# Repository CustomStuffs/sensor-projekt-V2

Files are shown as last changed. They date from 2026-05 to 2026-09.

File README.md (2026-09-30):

# Sensor Hub

Outdoor environmental monitoring system built on a Raspberry Pi Pico W. Sensors are read every 30 minutes, uploaded over WiFi to a FastAPI server running on a Raspberry Pi, and displayed in a browser dashboard.

## System overview

```
Pico W (MicroPython)
  └─ POST JSON ──► RPi FastAPI server (port 8080)
                      └─ SQLite DB
                      └─ Static files ──► Browser dashboard
```

Remote access via Tailscale VPN — no port forwarding, no auth layer needed.

## Sensors

| Sensor | Chip / interface | Board connection | Measures |
|---|---|---|---|
| Temperature | DS18B20, 1-Wire (GP8) | W1 (J2) | °C |
| Humidity | DHT22, GP9 | W2 (J3) | % RH + °C fallback |
| pH | AD8603 buffer → ADS1115 AIN0 (I2C, GP2/3) | BNC (J1), guarded input | pH 0–14 |
| Light | VEML7700, I2C (GP2/3) | on the board, under a light pipe to the lid | lux |
| Soil moisture | Capacitive, Pico ADC (GP26) | J11 solder holes (GP26–28) | % |
| Motion | PIR, GP11 (also wake IRQ), power-gated by GP12 | W3 (J4) | boolean |
| Water level | Float switch, GP16 | W4 (J5) | float |
| Probe temperature | NTC → ADS1115 AIN1 | J8 pins 3/4 | °C (for compensation) |
| EC | **not on the v1 board** (LMP91200 is EOL; firmware driver exists, keep `ec` disabled) | — | µS/cm |

All sensor fields are nullable — unconnected sensors send `null`.

## Relays (two on-board channels)

The PCB carries **two independent SPDT relays** (K1 on GP10, K2 on GP15), rated 230 VAC / 5 A with reinforced insulation to the sensor side, as a hard minimum. Both relays can be switched and scheduled from the dashboard, and local sensor rules can target either one (`"relay": 2` in a rule; default is relay 1). This allows two simultaneous actuator channels (e.g. pump + valve) without external modules. Future board variants can add more relays.

- **Auto rules**: threshold-based (e.g. water when soil < 30 %) configured in `firmware/src/config.json`
- **Schedule**: time-based rules, also in `config.json`
- **Manual override**: one-click from the dashboard, queued via server command API

## Repo layout

```
firmware/   MicroPython source + flash/dev tools
server/     FastAPI app, SQLite schema, systemd unit
dashboard/  Vanilla HTML/JS/CSS frontend
hardware/   KiCad project + generation scripts, BOM, JLCPCB order files
```

Each folder has its own `CLAUDE.md` with subproject-specific rules.

## Getting started

### Firmware

Requires MicroPython 1.28+ (`RPI_PICO_W` build).

```bash
cd firmware
bash tools/setup.sh          # install mpremote, check device
cp src/config.json.example src/config.json   # fill in WiFi + server URL
bash tools/flash.sh          # copy all files to device
bash tools/monitor.sh        # watch serial output
```

For daily development, use the mount workflow instead of reflashing:

```bash
bash tools/mount.sh   # edits in src/ take effect on Ctrl-D
```

### Server

```bash
cd server
pip install -r requirements.txt
uvicorn api.main:app --host 0.0.0.0 --port 8080
```

Or run as a systemd service:

```bash
sudo cp sensor_hub.service /etc/systemd/system/
sudo systemctl enable --now sensor_hub
```

### Dashboard

Served as static files by the FastAPI server — no build step. Open `http://<pi-ip>:8080` in a browser.

### Hardware

100 × 100 mm, 2-layer PCB (`hardware/kicad/`), generated and routed by the scripts in `hardware/tools/`. JLCPCB fabricates the board and places all SMD parts (`hardware/fab/`, regenerate with `python3 hardware/tools/jlc_export.py`); the through-hole parts — Pico WH sockets, relays, Wago push-in terminals, BNC, X2 capacitors, UART header — are hand-soldered. Details: `hardware/CLAUDE.md` and `hardware/docs/`.

## Pico W hardware notes

- **VSYS ADC**: use `ADC(29)` (GPIO29), not `ADC(3)`. On Pico W, GPIO29 is the VSYS/3 voltage divider. `ADC(3)` reads GPIO3 (I2C SCL) and gives garbage.
- **VSYS measurement timing**: read VSYS *before* `wlan.active(True)` — GPIO29 is shared with the WiFi SPI bus and returns wrong values while the radio is up.
- **Lightsleep after WiFi**: `machine.lightsleep(ms)` can fail silently on Pico W after WiFi use. The firmware falls back to `time.sleep()` automatically and logs when this happens.
- **Serial monitor**: uses `mpremote` (`bash tools/monitor.sh`), not minicom. On immutable distros (Bazzite/Silverblue), minicom is not available.
- **Flashing**: the device enters lightsleep ~30 s after boot, making `mpremote` unreachable. Flash immediately after plugging in USB, or interrupt via REPL first.

## Power budget (battery operation)

| State | Current |
|---|---|
| Lightsleep | 0.30 mA |
| Sensing (all sensors) | 25 mA |
| WiFi active | 80 mA |
| **Average (30 min cycle)** | **~1.2 mA** |

A 10 000 mAh power bank lasts roughly 6–11 months.

## License

MIT

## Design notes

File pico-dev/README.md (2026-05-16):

# Pico UART Debug Bridge

Two-Pico setup: **Machine Pico** (USB→PC) acts as a relay-reset + UART bridge
for the **Project Pico** (running the real firmware, never overwritten directly).

## Hardware

| Machine Pico | → | Project Pico |
|---|---|---|
| GPIO 4 (UART1 TX) | → | GPIO 1 (UART0 RX) |
| GPIO 5 (UART1 RX) | ← | GPIO 0 (UART0 TX) |
| GND | — | GND |
| GPIO 15 → Relay1 IN | | Relay1 COM → RUN pin, NO → GND |
| GPIO 28 → Relay2 IN | | Relay2 COM/NO → light circuit |

Both relays are active-LOW: GPIO LOW = relay closed.
- Relay1 (GPIO 15): pulls Project Pico RUN to GND → hard reset.
- Relay2 (GPIO 28): controls the light switch circuit.

## Quick Start

### 1. Flash the Machine Pico

Connect **only** the Machine Pico via USB.  Hold BOOTSEL, plug in → drag
`machine_pico/main.py` on using Thonny or mpremote:

```bash
mpremote connect /dev/ttyACM0 cp machine_pico/main.py :main.py
```

After reboot the Machine Pico prints `[bridge] ready …` on USB serial.

### 2. Install PC tool dependencies

```bash
pip install -r tools/requirements.txt
```

### 3. Use pico_tool.py

```bash
# Stream all Project Pico output live (also lets you type RESET / SEND:)
python tools/pico_tool.py monitor

# Hard-reset Project Pico via relay
python tools/pico_tool.py reset

# Copy a file to Project Pico (requires confirmation + Project Pico USB connected)
python tools/pico_tool.py flash firmware/src/main.py

# Force a specific port (skips auto-detect)
python tools/pico_tool.py --port /dev/ttyACM1 monitor
```

### 4. Add UART debug output to Project Pico (optional)

Copy `project_pico/uart_debug.py` to the Project Pico:

```bash
mpremote connect /dev/ttyACMx cp project_pico/uart_debug.py :uart_debug.py
```

Then make `uart_debug` the **first import** in `main.py`:

```python
import uart_debug   # must be first — mirrors all print() to UART

# ... rest of your firmware unchanged
```

All `print()` calls are now mirrored to UART0 and will appear in `pico_tool.py monitor`.
Call `uart_debug.tick()` once per loop iteration for a 10 s heartbeat.

## Command Protocol (Machine Pico ↔ PC)

These are the raw commands the Machine Pico understands over its USB serial.
`pico_tool.py` sends them automatically; you can also type them in monitor mode.

| Command | Effect |
|---|---|
| `RESET` | Closes relay1 100 ms → Project Pico RUN → GND → hard reset |
| `SEND:<text>` | Sends `<text>\r\n` to Project Pico via UART |
| `LIGHT_ON` | Closes relay2 (GPIO 28 LOW) → light on |
| `LIGHT_OFF` | Opens relay2 (GPIO 28 HIGH) → light off |
| `LIGHT_TOGGLE` | Toggles relay2 state |

## Flash Workflow (how `flash` works internally)

1. Confirms with user before touching anything
2. Sends `RESET` to Machine Pico (relay fires, Project Pico reboots)
3. Waits 2 s for MicroPython REPL to come up on Project Pico
4. Runs `mpremote connect <project-port> cp <file> :<file>` to copy the file

**Requirement**: the Project Pico must also be connected via USB during flashing
so mpremote can reach its filesystem.

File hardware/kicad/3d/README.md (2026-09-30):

# 3D models (not in git)

KiCad ships no 3D models for these parts, and the vendor models may not be
redistributed (vendor terms of use), so the STEP files are `.gitignore`d.
Download them once into this folder under exactly these names;
`tools/place_pcb.py` points the footprints at `${KIPRJMOD}/3d/<name>` and
sets rotation/offset for each.

| File name | Part | Used by | Source (format: STEP AP214) |
|---|---|---|---|
| `Wago_2601-1102.step` | Wago 2601-1102 | J9 | wago.com → product → CAD (partcommunity); entry "2601-1102 bis 2601-1112", pick 1102 |
| `Wago_2601-1103.step` | Wago 2601-1103 | J2–J6 | same entry, pick 1103 (not the colour-coded 2601-1103/987-100) |
| `Wago_2601-1104.step` | Wago 2601-1104 | J8 | same entry, pick 1104 |
| `Wago_236-403.step` | Wago 236-403 | J7, J10 | wago.com → 236-403 → CAD |
| `Omron_G2RL-14-E.step` | Omron G2RL-14-E DC5 | K1, K2 | TraceParts / omron.com (the sealed -14-E; same body and pins as the -1-E we fit) |
| `TE_BNC_1-1478035-0.step` | TE 1-1478035-0 | J1 | te.com → 1-1478035-0 → Customer View Model `…3d_stp.zip` |

Only the model files matter for the 3D view and the enclosure design; Gerbers
and the JLCPCB files do not depend on them.

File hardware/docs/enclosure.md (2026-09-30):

# Enclosure & Weatherproofing

---

## Primary Recommendation: Hammond 1554T2GYCL

| Attribute | Value |
|---|---|
| Part number | 1554T2GYCL |
| External dimensions | 115 × 65 × 40 mm |
| Material | Polycarbonate (PC) |
| IP rating | **IP67** (1 m submersion) |
| Lid | Clear polycarbonate |
| Color | Light grey body |
| PCB standoffs | 4× M3 brass inserts, 3 mm height |
| Approx. CHF | 8–12 (Distrelec / Conrad) |
| Screws | 4× M3 × 10 mm stainless |

The clear lid lets you see the status LED without drilling.

**Alternative**: Bopla Euromas II EM 220 F (IP65, 122 × 72 × 55 mm, ABS, more depth for wiring).

---

## Cable Entries

| Entry | Part | IP rating | Cable dia. | Qty | Notes |
|---|---|---|---|-----|---|
| Wago sensor cables | Wiska ClikPlug M16 | IP68 | 4–8 mm | 5 | One per sensor port W1–W5 (J2–J6) |
| NTC probe cable (J8) | Wiska ClikPlug M16 | IP68 | 4–8 mm | 1 | 2 wires used in v1 (EC wires unused); M20 if a 4-wire EC probe cable is kept for v2 |
| USB-C power | Bulgin PX0441/B/4M00 | IP68 | Panel mount | 1 | 5V input feedthrough |
| pH BNC external | Amphenol 31-221-RFX | IP67 | Panel mount | 1 | External probe connector |
| Relay mains cables (W6, W7) | Wiska ClikPlug M20 | IP68 | 8–14 mm | 2 | 230 VAC load cables; enter on the MAINS side of the box, away from sensor glands |

**Mains wiring inside the enclosure**: keep 230 VAC load cables on the MAINS side of the box, tied down so a loose conductor cannot reach the SELV side of the PCB. Double-insulated cable (sheath stripped only as far as needed at W6/W7). If the enclosure has any metal parts (e.g. mounting plate), they must be earthed by the electrician.

**⚠ Enclosure size**: the PCB is now **100 × 100 mm**; the Hammond 1554T2GYCL (115 × 65 × 40 mm external) above does **not** fit it, neither does the Bopla EM 220 F. The plan (see `pcb_guidelines.md`) is a 3D-printed enclosure; a bought box needs ≥ ~110 × 110 mm inside and ≥ ~25 mm clear height above the board.

---

## PCB Envelope (for the enclosure design)

Heights above the top of the PCB, from the vendor 3D models (`kicad/3d/`):

| Part | Where on the board | Height |
|---|---|---|
| BNC J1 (pH) | left edge, y 44–60, opening points out of the left edge | ≈ 19.2 mm (tallest) |
| Relays K1/K2 | right half, x 67–80 | 15.7 mm |
| Wago 2601 (J2–J6, J8, J9) | bottom edge row + J9 at the top edge | ≈ 15.1 mm, orange levers reach ~0.8 mm past the board edge |
| Pico WH on sockets | centre, USB-C at the top edge (x ≈ 40) | ≈ 8.5 mm socket + Pico + USB plug |
| Wago 236-403 (W6/W7) | right edge, y 15–51 | 12.7 mm |
| X2 caps C19/C20 | left of the relays | box 13 × 6 mm, check the fitted part |

- **Board mounting**: 4× M3 holes H1–H4 at (3.5, 3.5), (3.5, 96.5), (96.5, 96.5), (96.5, 3.5) mm from the top-left corner.
- **Wire entries**: all sensor terminals (J8, J2–J6) open toward the bottom edge, J9 (5 V) toward the top edge, W6/W7 (mains) toward the right edge — put the glands on those walls and keep the mains glands on the right wall only.
- **Light sensor window**: U6 (VEML7700) is at (45.0, 73.45) mm. A light pipe (acrylic/PMMA rod, ≈ 5–6 mm) runs from just above U6 (≤ 0.5 mm gap) straight up to a window/hole in the lid. Its 3D-printed holder screws to the board through 3× M2 holes H5 (45.0, 66.45), H6 (38.94, 76.95), H7 (51.06, 76.95); the holder base needs a recess for U6 (2.35 mm high) and C9 (3.2 mm below U6). Seal the rod in the lid (silicone or O-ring) and keep it opaque around the sides so only the window collects light.

---

## BNC Panel Mount

The PCB uses a right-angle PCB-mount BNC (TE 1-1478035-0) at the left board edge for internal connection. The external BNC on the enclosure wall is a separate panel-mount connector connected via a short RG174 coaxial pigtail (50–100 mm).

1. Drill a 10 mm hole in the enclosure wall at the BNC position
2. Insert panel-mount BNC (Amphenol 31-221-RFX), secure with lock nut and washer
3. Solder a 75–100 mm RG174 pigtail: center conductor to PCB BNC center pin, shield to PCB BNC shell / VREF_MID trace
4. Apply silicone sealant around the BNC nut on the outside

---

## Gore-Tex Vent Plug (mandatory for outdoor use)

**Part**: Wiska VMK 16 or equivalent IP67-rated vent plug.

**Why**: a fully sealed IP67 enclosure experiences pressure/temperature cycling outdoors. Without a vent, warm air inside the enclosure during the day creates condensation when it cools at night. The Gore-Tex membrane passes water vapor but not liquid water — preventing internal condensation without compromising weather protection.

Install one vent plug in the bottom face of the enclosure (lowest point for drainage if any moisture enters).

---

## Assembly Notes

1. Drill all holes using a step drill bit in polycarbonate — avoid twist drills (crack risk)
2. Install cable glands hand-tight, then 1/4 turn with pliers — do not overtighten
3. Apply silicone sealant (neutral cure, not acetic acid cure) around:
   - PCB standoff mounting screws
   - BNC lock nut
   - USB-C panel connector
4. Route sensor cables with a drip loop before entering cable glands (prevents water tracking)
5. Lid torque: finger-tight + 1/4 turn — overtightening cracks polycarbonate lid
6. Supplied gasket is replaceable; check condition annually if unit is in direct rain exposure
7. Label cable glands with UV-stable vinyl labels or permanent marker (sensor type)

---

## Mounting

Mount on a stake, post, or bracket using M3/M4 stainless bolts through the enclosure wall or base. Avoid mounting flat against a wall — leave at least 10 mm air gap behind for heat dissipation.

Orientation: BNC connector side toward the nearest sheltered location (garden wall, planter edge) to protect the pH probe connection from direct rain impact.

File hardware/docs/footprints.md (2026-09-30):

# KiCad Footprint Reference

Map every BOM line to its KiCad library footprint before starting schematic entry.
Checked against the KiCad **10.0** standard libraries (Sep 2026).
All footprints assigned. J1 was changed from Amphenol 031-6575 (an isolated BNC whose footprint splits shield and shell into separate pads) to TE 1-1478035-0 (all shield pads = pad 2). Project footprints: `sensor_hub:VEML7700_TT`.
Flags: ⚠ = verify against datasheet before placing; ✗ = DNP v1; **TBD** = not in the KiCad library, project footprint still to be drawn.

Project libraries live next to the project: `kicad/sensor_hub.kicad_sym` (symbols). A project footprint library `kicad/sensor_hub.pretty` will be added for the TBD footprints.

---

## ICs

| Ref | Part | Package | KiCad symbol | KiCad footprint |
|-----|---|---|---|---|
| U1 | Pico WH (SC0919) on sockets | 2× 1×20 THT, 2.54 mm | `MCU_Module:RaspberryPi_Pico_W` | `Module:RaspberryPi_Pico_Common_THT` |
| U2 | ADS1115IDGSR | VSSOP-10 | `Analog_ADC:ADS1115IDGS` | `Package_SO:MSOP-10_3x3mm_P0.5mm` |
| U4 | AD8603AUJZ | TSOT-23-5 | `Amplifier_Operational:AD8603` | `Package_TO_SOT_SMD:TSOT-23-5` |
| U5 | AP2112K-3.3TRG1 | SOT-23-5 | `Regulator_Linear:AP2112K-3.3` | `Package_TO_SOT_SMD:SOT-23-5` |
| U6 | VEML7700-TT | 4-pin, top view | `sensor_hub:VEML7700` (project) | `sensor_hub:VEML7700_TT` (project) |

**U2 note**: DGS suffix = VSSOP-10 (3×3 mm, 0.5 mm pitch). KiCad 10 names this land pattern `MSOP-10_3x3mm_P0.5mm` (same footprint).

**U3 / R15 / R16 / C3–C5**: EC front-end (LMP91200) removed from v1 (Sep 2026); designators retired.

**U4 note**: TSOT-23-5 = order code AD8603AUJZ (JLCPCB/LCSC C14937, AD8603AUJZ-REEL7). The old BOM entry "AD8603ARTZ-R2" is not a valid ADI part number.

**U6 note**: pinout 1 = SCL, 2 = VDD, 3 = GND, 4 = SDA and pad pattern (4 × 0.7 × 1.6 mm, pitch 1.27 mm, "Top View" layout) taken from Vishay datasheet 84286 Rev. 1.8, p. 1 and p. 10. Pin 1 is marked with a silk dot. The body outline on F.Fab is approximate — the datasheet gives no body-to-pad offset for top-view mounting; check against a real part before placing it near other parts.

---

## Discretes

| Ref | Part | Package | KiCad footprint |
|-----|---|---|---|
| D1 | BAV99 | SOT-23 | `Package_TO_SOT_SMD:SOT-23` |
| D2, D3 | 1N4148W | SOD-123 | `Diode_SMD:D_SOD-123` |
| Q1, Q3 | BC817-40 | SOT-23 | `Package_TO_SOT_SMD:SOT-23` |
| Q2 | BSS84PXUMA1 | SOT-23 | `Package_TO_SOT_SMD:SOT-23` |
| K1, K2 | Omron G2RL-1-E DC5 | THT relay | `Relay_THT:Relay_SPDT_Omron_G2RL-1-E` (symbol `Relay:G2RL-1-E`) |

**K1/K2 note**: both symbol and footprint are in the KiCad 10 library. Confirm coil pins and COM/NO/NC pin numbers against the Omron datasheet before routing. Add the 2 mm isolation slot (Edge.Cuts) between coil and contact pins on the board.

---

## Passives

| Ref | Value | Package | KiCad footprint |
|-----|---|---|---|
| R1–R3, R5–R11, R17, R18 | various | 0603 | `Resistor_SMD:R_0603_1608Metric` |
| R4 | — | — | intentionally unused |
| R19–R20 | 100 Ω snubber | 1206 | `Resistor_SMD:R_1206_3216Metric` |
| C1–C2, C6–C12 | 100 nF | 0603 | `Capacitor_SMD:C_0603_1608Metric` |
| C13–C16 | 10 µF | 0805 | `Capacitor_SMD:C_0805_2012Metric` |
| C17–C18 | 1 µF | 0603 | `Capacitor_SMD:C_0603_1608Metric` |
| C19–C20 | 100 nF X2 film | THT box 13×6 mm, 10 mm pitch | `Capacitor_THT:C_Rect_L13.0mm_W6.0mm_P10.00mm_FKS3_FKP3_MKS4` ⚠ verify body size of chosen part |

---

## Connectors

| Ref | Part | Type | KiCad footprint |
|-----|---|---|---|
| J1 | TE 1-1478035-0 | RA BNC, 4 pins (1 = center, all others = shield) | `Connector_Coaxial:BNC_TEConnectivity_1478035_Horizontal` (symbol `Connector:Conn_Coaxial`) |
| J2–J6 | Wago 2601-1103 | THT 3-pole 3.5 mm (SELV sensors W1–W5) | `TerminalBlock_WAGO:TerminalBlock_WAGO_2601-1103_1x03_P3.50mm_Horizontal` |
| J7, J10 | Wago 236-403 | THT 3-pole 5 mm, mains (W6/W7), 24 A IEC / 300 V UL | `TerminalBlock_WAGO:TerminalBlock_WAGO_236-403_1x03_P5.00mm_45Degree` |
| J8 | Wago 2601-1104 | THT 4-pole push-in 3.5 mm | `TerminalBlock_WAGO:TerminalBlock_WAGO_2601-1104_1x04_P3.50mm_Horizontal` |
| J9 | Wago 2601-1102 | THT 2-pole push-in 3.5 mm | `TerminalBlock_WAGO:TerminalBlock_WAGO_2601-1102_1x02_P3.50mm_Horizontal` |
| HDR1 | PEC04SAAN | 2.54 mm 1×4 | `Connector_PinHeader_2.54mm:PinHeader_1x04_P2.54mm_Vertical` |
| J11 | — (DNP, holes only) | 2.54 mm 2×8 | `Connector_PinHeader_2.54mm:PinHeader_2x08_P2.54mm_Vertical` |

---

## Mechanical

| Ref | Part | KiCad footprint | Notes |
|-----|---|---|---|
| H1–H4 | M3 board mounting | `MountingHole:MountingHole_3.2mm_M3` | corners, no copper |
| H5–H7 | M2 light-pipe holder | `MountingHole:MountingHole_2.2mm_M2` | around U6 on r = 7 mm, no copper, reference hidden |

## 3D models

KiCad has no 3D models for the Wago terminals (2601-1102/-1103/-1104, 236-403), the G2RL relay (SPDT) and the TE BNC. `tools/place_pcb.py` points those footprints at vendor STEP files in `kicad/3d/` (with rotation/offset worked out from the pin positions in the STEP data). The STEP files are not in git (vendor terms, public repo) — download list in `kicad/3d/README.md`. U6 (VEML7700, project footprint) has no 3D model yet.

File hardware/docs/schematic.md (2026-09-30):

# Schematic — Pico W Sensor Hub

Use this as the reference for KiCad entry. Every connection in `bom.csv` traces back here.

**Design decision (Aug 2026):** Minimum two on-board relays (K1 + K2). The board must support at least two independent actuator channels (pump, valve, etc.) without external modules. Future variants can add more relays; this is the baseline.

**Also required:** Guard ring on the pH high-Z node + RC snubbers on both relay contact sets for EMC.

**Connector decision:** Both relay contact sets use mains-rated Wago 3-pin connectors (W6 = Relay 1, W7 = Relay 2) at the right board edge next to the relays, inside the MAINS zone and separated from sensor ports W1–W5. No separate screw terminals next to the relays.

**Mains decision (Sep 2026):** Relay contacts are rated for **230 VAC, 5 A per channel** (anything up to 48 V DC is covered too). Relays are Omron G2RL-1-E with reinforced coil–contact insulation. All relay contact nets belong to the `MAINS` netclass and need ≥ 8 mm creepage/clearance to every other net — see `pcb_guidelines.md` → Relay Zone Rules.

---

## System Block Diagram

```
USB-C 5V (power bank)
│
├─ VSYS ──────────────────────────────── Pico W VSYS
│                                         K1 + K2 coil (+)
│                                         AP2112K IN ── AP2112K OUT (Analog 3V3) ─── ADS1115, AD8603, VREF divider, NTC pullup
│
└─ Pico W 3V3(OUT)
     └─ Digital 3V3 ─── VEML7700, DS18B20, DHT22, PIR, pull-ups

(AP2112K is fed from VSYS, not from 3V3_DIG — a 3.3 V LDO cannot regulate from a 3.3 V input.)

I2C Bus (GP2/GP3, 4.7kΩ pullups to 3V3_DIG)
  ├── ADS1115  addr 0x48 (ADDR pin → GND)
  └── VEML7700 addr 0x10 (fixed; no ADDR pin)

SPI Bus (GP4/GP5/GP6/GP7): not used in v1 — reserved on J11 for the v2 EC front-end

1-Wire (GP8, 4.7kΩ pullup to 3V3_DIG)
  └── DS18B20 temperature sensor (Wago port 1)

GPIO direct:
  GP9  ── DHT22 data (Wago port 2, 10kΩ pullup)
  GP10 ── Relay 1 driver (→ Q1 BC817 base)
  GP11 ── PIR output (Wago port 3, 10kΩ pullup, wake IRQ)
  GP12 ── PIR MOSFET gate (power gate for PIR)
  GP13, GP14 ── unused in v1 (were the EC excitation PWM outputs; left unconnected)
  GP15 ── Relay 2 driver (→ Q3 BC817 base)
  GP16 ── Wago port 4 signal (generic)
  GP17 ── Wago port 5 signal (generic)
  GP4–GP7, GP18–GP22, GP26–GP28, RUN ── J11 spare-GPIO solder holes (GP4–GP7 reserved for the v2 EC front-end SPI)
```

---

## Net List

### Power Nets

| Net | Source | Destinations |
|-----|---|---|
| VSYS | USB-C VBUS | Pico W VSYS, K1 coil (+), K2 coil (+), AP2112K VIN |
| 3V3_DIG | Pico W 3V3(OUT) | VEML7700 VCC, DS18B20 VDD, DHT22 VDD, BC817 pull, I2C pullup tops |
| 3V3_ANA | AP2112K VOUT | ADS1115 VDD+AVDD, AD8603 VS+, VREF_TOP (pH divider), NTC pullup top |
| GND_DIG | Pico W GND | All digital IC GND, Q1/Q3 emitters, K1/K2 coil (–) via collectors |
| GND_ANA | ADS1115 AGND | AD8603 VS–, pH divider bottom, NTC low side |
| VREF_MID | pH divider midpoint | BNC shield, AD8603 IN– via 100kΩ, C_vref 100nF to GND_ANA |

Single-point AGND/DGND join at the ADS1115 GND pin, implemented as net tie **NT1** (GND_ANA ↔ GND). Optional: replace with 0Ω link or ferrite bead.
The AP2112K (U5) GND and its input caps C14/C17/C8 sit on GND_ANA; the VSYS entry caps C13/C11 sit on GND.
Pico W AGND (pin 33) is tied to GND (Pico ADC unused). KiCad ERC flags this as "power output to power output" — expected, can be excluded.

---

## pH Analog Frontend + Guard Ring

```
BNC_CENTER ──── R1(10MΩ) ──── NODE_A ──── AD8603 IN+
                                │
                             BAV99 (SOT-23)
                                │ Pin3 (common) = NODE_A
                                │ Pin1 (anode)  → GND_ANA
                                │ Pin2 (cathode) → 3V3_ANA

3V3_ANA ── R2(100kΩ) ── NODE_VREF ── R3(100kΩ) ── GND_ANA
                              │
                           C1(100nF) → GND_ANA      [filter cap]

AD8603 OUT ──── AD8603 IN– (direct, unity-gain voltage follower)
AD8603 OUT ──── ADS1115 AIN0

BNC_SHIELD ──── NODE_VREF   (reference electrode biased at 1.65V)

AD8603 VS+  ──── 3V3_ANA + C2(100nF) to GND_ANA
AD8603 VS–  ──── GND_ANA
```

**Design decision (Sep 2026):** the former R4 (100 kΩ from NODE_VREF to AD8603 IN–) is removed. With IN– tied to OUT it only injected a small error current into the output. The reference offset comes from the BNC shield sitting on NODE_VREF. Reference R4 is intentionally unused.

**Transfer function**: pH electrode output ±414 mV (pH 0–14 at 25°C) is offset by VREF = 1.65V.
ADS1115 AIN0 sees 1.236V (pH 0) to 2.064V (pH 14). Use ±2.048V PGA setting.

### Guard-Ring Implementation (mandatory)

NODE_A (the net between R1 and AD8603 IN+) is a high-impedance node. Any surface leakage on the PCB corrupts the pH reading.

**Layout rule:**
- Surround the entire NODE_A trace with a continuous copper guard ring on **both** top and bottom layers.
- Connect the guard ring **only** to AD8603 OUT (the unity-gain buffered output).
- Do **not** connect the guard to GND or to any other net.
- Keep the guard ring as close as practical to the NODE_A trace (typically 0.2–0.5 mm gap).
- No other traces may cross the guarded area without a keep-out.

This makes the potential difference between NODE_A and the surrounding copper almost zero → leakage current becomes negligible.

---

## EC Measurement — not in v1

> The LMP91200 EC front-end is EOL/unavailable (May 2026). In v1 it is **removed from the
> schematic and the board**, together with its PWM RC filters and decoupling (U3, R15, R16,
> C3, C4, C5; Sep 2026). GP13/GP14 are unused. v2 plans an AD5933 impedance converter
> (own excitation, I2C/SPI); GP4–GP7 stay free on J11 for it. The designators U3, R15, R16,
> C3, C4, C5 are retired, not reused.

```
EC 4-wire terminal (J8, Wago 2601-1104 push-in):
  Pin 1 (White) ── not connected in v1 (was EC Working Electrode)
  Pin 2 (Yellow) ── not connected in v1 (was EC Reference Electrode)
  Pin 3 (Red)   ── NTC thermistor signal → NODE_NTC
  Pin 4 (Black) ── NTC GND → GND_ANA
```

### NTC Thermistor Divider

```
3V3_ANA ── R7(10kΩ) ── NODE_NTC ── J8 Pin3 (NTC hot side)
                           │
                        C6(100nF) to GND_ANA    [anti-alias]
                           │
                        ADS1115 AIN1

J8 Pin4 (NTC GND) ── GND_ANA
```

---

## ADS1115 Channel Assignments

| Channel | Signal | Sensor |
|---|---|---|
| AIN0 | pH buffer output (AD8603 OUT) | pH electrode |
| AIN1 | NTC divider (NODE_NTC) | NTC temperature probe on J8 |
| AIN2 | not connected (no-connect in the schematic) | — |
| AIN3 | not connected (no-connect in the schematic) | — |

W4/W5 only carry the digital GP16/GP17. An analog sensor (e.g. capacitive soil moisture) goes to the Pico's own ADC on GP26–GP28, which are brought out on the J11 solder holes.

ADS1115 I2C address: 0x48 (ADDR pin → GND_DIG)

---

## Relay Drivers + Contact EMC Snubbers (two channels)

Both relays are SPDT PCB-mount **Omron G2RL-1-E DC5** (5 V coil ≈ 80 mA from VSYS, contacts 16 A 250 VAC, 5 kVAC reinforced coil–contact insulation). Do not substitute a relay with only basic coil–contact insulation (e.g. Songle SRD series) — the SELV side connects to probes in water. Contact nets (COM/NO/NC, snubber midpoints, W6/W7) are in netclass `MAINS`: ≥ 8 mm creepage and clearance to any coil, logic or sensor net.

### Relay 1 (K1) — GP10

```
GP10 ── R8(1kΩ) ── Q1(BC817) BASE
Q1 EMITTER ──────── GND_DIG
Q1 COLLECTOR ─┬──── K1 coil (–)
              └──── D2(1N4148) cathode
K1 coil (+) ──┴──── D2(1N4148) anode ──── VSYS

K1 NO  ─── W6 (J7) pin 1
K1 COM ─── W6 (J7) pin 2
K1 NC  ─── W6 (J7) pin 3      (order follows the board: straight mains tracks)

# Contact EMC snubber (across the switched path)
K1 COM ── R19(100Ω) ── C19(100nF) ── K1 NO
```

### Relay 2 (K2) — GP15

```
GP15 ── R18(1kΩ) ── Q3(BC817) BASE
Q3 EMITTER ──────── GND_DIG
Q3 COLLECTOR ─┬──── K2 coil (–)
              └──── D3(1N4148) cathode
K2 coil (+) ──┴──── D3(1N4148) anode ──── VSYS

K2 NC  ─── W7 (J10) pin 1
K2 COM ─── W7 (J10) pin 2
K2 NO  ─── W7 (J10) pin 3     (K2 is rotated 180°, so the order is mirrored)

# Contact EMC snubber
K2 COM ── R20(100Ω) ── C20(100nF) ── K2 NO
```

**Snubber notes:**
- Series RC across COM–NO suppresses arcing and EMI when switching inductive loads (pumps, solenoids, valves).
- C19/C20 are **X2-rated film capacitors (100 nF, 275 VAC)** because the contacts may switch 230 VAC. R19/R20 are 1206 (≥ 200 V working voltage), not 0603.
- Place the snubber components as close as possible to the relay contact pins, inside the MAINS zone.
- At 230 V / 50 Hz the snubber passes ≈ 7 mA with the contact open. For LED lamps or small contactor coils that react to this, leave that channel's snubber unpopulated.
- Each channel must be protected upstream by a fuse/MCB ≤ 6 A (installation side).

---

## Wago / Terminal Ports

| Port | Pin 1 | Pin 2 | Pin 3 | Default sensor / function |
|---|---|---|---|---|
| W1 (J2) | 3V3_DIG | GND_DIG | GP8 (1-Wire) | DS18B20 temperature |
| W2 (J3) | 3V3_DIG | GND_DIG | GP9 (DHT data) | DHT22 temp+humidity |
| W3 (J4) | PIR_VCC (3V3 switched by Q2) | GND_DIG | GP11 (PIR out) | PIR motion |
| W4 (J5) | 3V3_DIG | GND_DIG | GP16 | Generic digital (e.g. float switch) |
| W5 (J6) | 3V3_DIG | GND_DIG | GP17 | Generic |
| W6 (J7) | K1 NO | K1 COM | K1 NC | Relay 1 SPDT contacts — **MAINS, 230 VAC / 5 A** |
| W7 (J10) | K2 NC | K2 COM | K2 NO | Relay 2 SPDT contacts — **MAINS, 230 VAC / 5 A** |

- **J8** (4-pole, label `J8  EC W Y R B`): pin 1 and 2 not connected (were EC WE/RE), pin 3 NTC+ → NODE_NTC, pin 4 NTC– → GND_ANA.
- **J9** (2-pole, label `5V IN`): pin 1 VSYS, pin 2 GND.

All actuator and sensor connections use push-in Wago terminals for a consistent interface. W1–W5 are SELV sensor ports (Wago 2601-1103, 3.5 mm), J8/J9 are Wago 2601-1104/-1102 from the same push-in family; W6/W7 are mains-rated 3-pole THT terminals (Wago 236-403, 5 mm, 2.5 mm²) in the separate MAINS zone.

**PIR power gate**: Q2 (BSS84, SOT-23 P-channel MOSFET) controlled by GP12 switches the 3V3 supply to the PIR on Wago port 3. This avoids the 50–65 mA PIR standby current during sleep.
- Source → 3V3_DIG, Drain → PIR VCC (Wago port 3 pin 1), Gate → GP12
- R17 (10 kΩ) pulls gate to 3V3_DIG so FET is OFF (PIR off) when GP12 is floating at boot
- GP12 LOW = Vgs −3.3 V = FET ON; GP12 HIGH = Vgs 0 V = FET OFF

---

## Decoupling Summary

| Location | Cap value | Refs | Notes |
|---|---|---|---|
| VSYS entry (J9) | 10 µF + 100 nF | C13 + C11 | Before anything else |
| AP2112K input (VSYS) | 10 µF + 1 µF + 100 nF | C14 + C17 + C8 | |
| AP2112K output (3V3_ANA) | 10 µF + 1 µF + 100 nF | C15 + C18 + C12 | Per datasheet |
| ADS1115 VDD | 10 µF + 100 nF | C16 + C7 | AVDD and VDD pins |
| AD8603 VS+ | 100 nF | C2 | Within 0.5 mm of pin |
| VEML7700 VDD | 100 nF | C9 | |
| VREF_MID | 100 nF to GND_ANA | C1 | Filters virtual mid-rail |
| NTC node | 100 nF to GND_ANA | C6 | Anti-alias |
| Relay coils (VSYS at K1/K2) | 100 nF | C10 | Local decoupling next to the coils |
| BC817 collector traces | — | — | No cap; keep traces short |
| Relay contact snubbers | 100 nF X2 | C19 / C20 | Across COM–NO of each relay, series with R19 / R20 100 Ω |

---

## Reference Designators (master list)

Single source for every reference. KiCad schematic, `bom.csv` and `footprints.md` must match this table.

| Ref | Value | Function |
|-----|---|---|
| U1 | Pico WH | MCU module, plugged into 2× 1×20 female headers |
| U2 | ADS1115IDGSR | 16-bit ADC, I2C 0x48 |
| U4 | AD8603 | pH unity-gain buffer |
| U5 | AP2112K-3.3 | 3V3_ANA LDO, input from VSYS |
| U6 | VEML7700 | Ambient light, I2C 0x10; under a light pipe, see pcb_guidelines.md |
| J1 | BNC | pH probe input (shield → NODE_VREF) |
| J2–J6 | Wago 3-pin | Sensor ports W1–W5 (SELV) |
| J7 | Wago 3-pole mains | W6 = Relay 1 COM/NO/NC |
| J8 | Wago 2601-1104 | EC/NTC probe (only pins 3–4 NTC used in v1) |
| J9 | Wago 2601-1102 | VSYS + GND input |
| J10 | Wago 3-pole mains | W7 = Relay 2 COM/NO/NC |
| HDR1 | 1×4 header | Debug UART0 (GP0 TX, GP1 RX, GND, 3V3) |
| J11 | 2×8 holes (DNP) | Spare-GPIO breakout: 1 GP4, 2 GP5, 3 GP6, 4 GP7, 5 GP18, 6 GP19, 7 GP20, 8 GP21, 9 GP22, 10 GP26, 11 GP27, 12 GP28, 13 RUN, 14 3V3_DIG, 15–16 GND |
| K1, K2 | G2RL-1-E DC5 | Relays 1 and 2 |
| Q1, Q3 | BC817-40 | Relay 1 / Relay 2 coil drivers |
| Q2 | BSS84 | PIR power gate |
| D1 | BAV99 | pH input clamp (pin 3 common → NODE_A) |
| NT1 | Net tie | Single-point join GND_ANA ↔ GND at ADS1115 |
| D2, D3 | 1N4148W | Relay 1 / Relay 2 flyback |
| R1 | 10 MΩ | pH series input (BNC center → NODE_A) |
| R2, R3 | 100 kΩ | VREF divider top / bottom |
| R4 | — | Intentionally unused (removed Sep 2026) |
| R5 | 4.7 kΩ | 1-Wire pull-up GP8 → 3V3_DIG |
| R6 | 10 kΩ | DHT22 pull-up GP9 → 3V3_DIG |
| R7 | 10 kΩ | NTC pull-up 3V3_ANA → NODE_NTC |
| R8 | 1 kΩ | Q1 base (GP10) |
| R9 | 10 kΩ | PIR output pull-up GP11 → 3V3_DIG |
| R10, R11 | 4.7 kΩ | I2C pull-ups SDA/SCL → 3V3_DIG |
| R17 | 10 kΩ | Q2 gate pull-up |
| R18 | 1 kΩ | Q3 base (GP15) |
| R19, R20 | 100 Ω 1206 | Relay 1 / Relay 2 snubber |
| C1, C2, C6–C20 | see Decoupling Summary | C3, C4, C5 retired (EC front-end removed) |

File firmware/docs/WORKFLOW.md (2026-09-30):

# Pico W Firmware Development Workflow

## One-Time Setup

### 1. Flash MicroPython to the Pico W

1. Hold the **BOOTSEL** button on the Pico W while plugging in USB.
2. The device appears as a USB drive named `RPI-RP2`.
3. Download the latest MicroPython UF2 for **Pico W** (not the generic RP2040 build):
   `https://micropython.org/download/RPI_PICO_W/`
   (Current stable: v1.28.0 — `RPI_PICO_W-20241025-v1.28.0.uf2`)
4. Drag the UF2 file onto the `RPI-RP2` drive.
5. The Pico W reboots automatically. MicroPython is now running.

### 2. Install dev tools

```bash
./tools/setup.sh
```

This installs `mpremote` and checks that `/dev/ttyACM0` is detected.

---

## Daily Development Loop

Use `mount.sh` — it mounts your local `src/` directory on the device without copying files. Edit normally in your editor; press Ctrl-D in the mpremote terminal to reload.

```bash
./tools/mount.sh
```

Inside the mpremote session:
- **Ctrl-D** — soft-reset and re-run `main.py` (picks up your latest edits instantly)
- **Ctrl-X** — exit mpremote cleanly

> **WARNING — filesystem corruption bug (MicroPython issue #10898)**
> After pressing Ctrl-D, wait for the `>>>` prompt before pressing Ctrl-C.
> Pressing Ctrl-C immediately after Ctrl-D triggers a known bug that can corrupt
> the entire Pico W filesystem. If that happens, re-flash MicroPython via BOOTSEL.

---

## Inspecting the Device

Open a REPL to run snippets, check sensor values, or poke at module state:

```bash
./tools/repl.sh
```

Useful REPL snippets:

```python
# Check config
import json
with open('config.json') as f: print(json.load(f))

# Read temperature manually
from drivers.ads1115 import ADS1115
from machine import I2C, Pin
i2c = I2C(1, sda=Pin(2), scl=Pin(3))
adc = ADS1115(i2c)
print(adc.read(0))   # AIN0 = pH buffer output

# Check WiFi
import network
wlan = network.WLAN(network.STA_IF)
wlan.active(True)
print(wlan.scan())
```

---

## Monitoring Serial Output

Watch `print()` output from `main.py` without entering the REPL:

```bash
./tools/monitor.sh             # uses /dev/ttyACM0
./tools/monitor.sh /dev/ttyACM1   # if ACM0 is wrong
```

Exit: **Ctrl-A then X**.

---

## Resetting the Device

Soft-reset (reruns `main.py`, same as Ctrl-D in the REPL):

```bash
./tools/reset.sh
```

---

## Deploying a Release Build

When development is done, copy all files to device flash (no more live mount):

```bash
./tools/flash.sh
```

This runs `mpremote cp -r src/ :` then `mpremote reset`. After reset the device runs standalone without a USB connection.

---

## Calibration Procedures

### pH (2-point calibration)

1. Edit `config.json` → `calibration.ph`:

```json
"ph": {
  "v_at_ph4": 1.855,
  "v_at_ph7": 1.650
}
```

2. Measure the actual ADS1115 voltage for each buffer solution:
   - pH 4.01 buffer → record voltage as `v_at_ph4`
   - pH 7.00 buffer → record voltage as `v_at_ph7`
3. The slope is `(7 - 4) / (v_at_ph7 - v_at_ph4)` — pH increases as voltage decreases.

### EC (1-point calibration)

> Needs an EC front-end, which the v1 board does not have (LMP91200 removed, EOL). Keep `sensors.ec.enabled = false` on v1 hardware.

1. Use 1413 µS/cm standard solution at a known temperature (25 °C ideal).
2. Edit `config.json` → `calibration.ec`:

```json
"ec": {
  "cell_constant": 1.0,
  "ref_voltage": 1.65,
  "ref_temp_c": 25.0
}
```

3. Adjust `cell_constant` until the reported value matches 1413 µS/cm.

### Soil moisture (2-point calibration)

1. Read raw ADC count in dry air → `dry_count`
2. Submerge sensor in water → `wet_count`
3. Edit `config.json` → `calibration.soil`:

```json
"soil": {
  "dry_count": 26000,
  "wet_count": 13000
}
```

---

## Running Desktop Unit Tests

The calibration math can be tested on any desktop Python (no hardware needed):

```bash
python3 firmware/tests/test_calibration.py
```

---

## Recovering a Boot-Looping Pico

If `main.py` crashes before the REPL loads and the device is stuck in a crash loop:

1. Hold **BOOTSEL**, plug in USB → `RPI-RP2` drive appears.
2. Flash the same MicroPython UF2 again.
3. This overwrites the filesystem — your code is gone. Re-flash with `./tools/flash.sh`.

To avoid this: always test new code changes in the REPL (`./tools/repl.sh`) before writing to `main.py`.

---

## GPIO Pinout Reference

Source: `hardware/docs/schematic.md` (v1 board).

| GPIO | Function | Notes |
|---|---|---|
| GP0 | UART0 TX | Debug header HDR1 pin 1 |
| GP1 | UART0 RX | Debug header HDR1 pin 2 |
| GP2 | I2C1 SDA | ADS1115 (0x48) + VEML7700 (0x10); 4.7 kΩ pull-up R10 |
| GP3 | I2C1 SCL | ADS1115 + VEML7700; 4.7 kΩ pull-up R11 |
| GP4–GP7 | free | J11 solder holes 1–4; reserved for a v2 EC front-end. Not connected to anything on the v1 board — the LMP91200 SPI code in firmware has no hardware |
| GP8 | 1-Wire | DS18B20, Wago W1 (J2); 4.7 kΩ pull-up R5 |
| GP9 | DHT_DATA | DHT22, Wago W2 (J3); 10 kΩ pull-up R6 |
| GP10 | RELAY1_DRV | K1 via Q1 (BC817) + 1 kΩ R8 |
| GP11 | PIR_OUT | PIR output + wake IRQ, Wago W3 (J4); 10 kΩ pull-up R9 |
| GP12 | PIR_EN_N | PIR power gate Q2 (BSS84): LOW = PIR on; R17 pulls it off at boot |
| GP13, GP14 | not connected | were the EC excitation PWM outputs; EC is not on the v1 board |
| GP15 | RELAY2_DRV | K2 via Q3 (BC817) + 1 kΩ R18 |
| GP16 | W4_SIG | Wago W4 (J5), generic digital (e.g. float switch) |
| GP17 | W5_SIG | Wago W5 (J6), generic digital |
| GP18–GP22 | free | J11 solder holes 5–9 |
| GP26–GP28 | free, ADC0–2 | J11 solder holes 10–12 (0–3.3 V analog, e.g. capacitive soil sensor on GP26) |
| RUN | RUN | J11 hole 13 |

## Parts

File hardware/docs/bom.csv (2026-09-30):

ref | description | part_number | manufacturer | qty | unit_chf | ext_chf | distributor | notes | lcsc
U1 | Raspberry Pi Pico WH (pre-soldered headers) | SC0919 | Raspberry Pi | 1 | 6.50 | 6.50 | Distrelec / Mouser | Pico W with headers; plugs into U1 sockets; price est.
U1-SKT | Female header 1x20 2.54mm THT (socket for Pico WH) | generic 1x20 female, 8.5 mm | various | 2 | 0.60 | 1.20 | Distrelec / Mouser | Two sockets for U1 footprint RaspberryPi_Pico_Common_THT; price est.
U2 | 16-bit I2C ADC 4ch VSSOP-10 | ADS1115IDGSR | Texas Instruments | 1 | 1.50 | 1.50 | Mouser 595-ADS1115IDGSR | I2C addr 0x48 (ADDR to GND) | C37593
U4 | Op-amp FET-in rail-to-rail TSOT-23-5 | AD8603AUJZ-REEL7 | Analog Devices | 1 | 1.20 | 1.20 | LCSC / Mouser 584-AD8603AUJZ-REEL7 | pH unity-gain buffer; single supply 3.3V (order code AUJZ = TSOT-23-5; "ARTZ" does not exist) | C14937
U5 | LDO 3.3V 600mA SOT-23-5 | AP2112K-3.3TRG1 | Diodes Inc. | 1 | 0.40 | 0.40 | Mouser 621-AP2112K-3.3TRG1 | Separate analog 3V3 rail | C51118
D1 | Dual series ESD diode SOT-23 | BAV99 | Nexperia | 1 | 0.10 | 0.10 | Mouser 771-BAV99215 | pH input protection (GND / VCC clamp) | C2500
D2 | Signal diode SOD-123 | 1N4148W | Vishay | 1 | 0.05 | 0.05 | Mouser 78-1N4148W-E3-08 | Relay 1 flyback | C81598
D3 | Signal diode SOD-123 | 1N4148W | Vishay | 1 | 0.05 | 0.05 | Mouser 78-1N4148W-E3-08 | Relay 2 flyback | C81598
Q1 | NPN BJT SOT-23 | BC817-40 | ON Semiconductor | 1 | 0.10 | 0.10 | Mouser 512-BC817-40LT1G | Relay 1 driver | C52801
Q3 | NPN BJT SOT-23 | BC817-40 | ON Semiconductor | 1 | 0.10 | 0.10 | Mouser 512-BC817-40LT1G | Relay 2 driver | C52801
K1 | SPDT relay 5V coil 16A PCB mount reinforced | G2RL-1-E DC5 | Omron | 1 | 2.50 | 2.50 | Mouser 653-G2RL-1-E-DC5 | 5V coil ≈80 mA from VSYS; 16 A 250 VAC; 5 kVAC reinforced coil-contact (required for 230 VAC next to SELV); price est.
K2 | SPDT relay 5V coil 16A PCB mount reinforced | G2RL-1-E DC5 | Omron | 1 | 2.50 | 2.50 | Mouser 653-G2RL-1-E-DC5 | Second on-board relay (minimum requirement); same part as K1
J1 | BNC female right-angle PCB mount 50 Ohm | 1-1478035-0 | TE Connectivity | 1 | 2.50 | 2.50 | Mouser / Distrelec | pH sensor connector; shell = shield = VREF_MID (not GND); KiCad footprint BNC_TEConnectivity_1478035_Horizontal; price est.
J2-J6 | Wago 3-pole push-in PCB terminal 3.5mm pitch (SELV sensors) | 2601-1103 | Wago | 5 | 0.90 | 4.50 | Distrelec / Wago direct | Sensor ports W1-W5 (SELV side only); price est.
J7 J10 | Wago 3-pole CAGE CLAMP PCB terminal 5mm pitch 45° | 236-403 | Wago | 2 | 1.20 | 2.40 | Distrelec / Wago direct | Relay ports W6 = J7 (K1) + W7 = J10 (K2) in MAINS zone; 2.5 mm²; 24 A (IEC) / 300 V 15 A (UL); price est.
J8 | Wago 4-pole push-in PCB terminal 3.5mm pitch | 2601-1104 | Wago | 1 | 1.10 | 1.10 | Distrelec / Wago direct | NTC probe on pins 3-4 (EC pins 1-2 unused in v1); same 2601 family as J2-J6 (was Phoenix screw terminal); price est.
R1 | Resistor 10M 0603 1% | RC0603FR-0710ML | Yageo | 1 | 0.05 | 0.05 | Mouser 603-RC0603FR-0710ML | pH series input (BNC center → NODE_A); inside guard ring | C7250
R2-R3 | Resistor 100k 0603 1% | RC0603FR-07100KL | Yageo | 2 | 0.02 | 0.04 | Mouser 603-RC0603FR-07100KL | VREF divider (NODE_VREF); R4 intentionally unused | C25803
R6 R7 R9 R17 | Resistor 10k 0603 1% | RC0603FR-0710KL | Yageo | 4 | 0.02 | 0.08 | Mouser 603-RC0603FR-0710KL | R6 DHT22 pull-up; R7 NTC pull-up; R9 PIR out pull-up; R17 BSS84 gate pull-up | C25804
R5 R10 R11 | Resistor 4.7k 0603 1% | RC0603FR-074K7L | Yageo | 3 | 0.02 | 0.06 | Mouser 603-RC0603FR-074K7L | R5 1-Wire pull-up; R10/R11 I2C pull-ups | C23162
R8 R18 | Resistor 1k 0603 1% | RC0603FR-071KL | Yageo | 2 | 0.02 | 0.04 | Mouser 603-RC0603FR-071KL | Relay base drive (R8 → Q1, R18 → Q3) | C21190
R19-R20 | Resistor 100R 1206 1% | RC1206FR-07100RL | Yageo | 2 | 0.05 | 0.10 | Mouser 603-RC1206FR-07100RL | Relay contact snubber resistors (series with C19/C20); 1206 for mains (200 V working) | C17901
C1-C2 C6-C12 | Cap 100nF 0603 X7R 25V | GRM188R71E104KA01D | Murata | 9 | 0.05 | 0.45 | Mouser 81-GRM188R71E104KA1D | C1 VREF; C2 AD8603; C6 NTC; C7 ADS1115; C8 LDO in; C9 VEML7700; C10 relay coils; C11 VSYS entry; C12 LDO out | C14663
C13-C16 | Cap 10uF 0805 X5R 10V (25V part fitted by JLC) | GRM21BR61A106KE18L | Murata | 4 | 0.10 | 0.40 | Mouser 81-GRM21BR61A106KE8L | 10 µF bulk: C13 VSYS entry; C14 LDO in; C15 LDO out; C16 ADS1115 VDD | C15850
C17-C18 | Cap 1uF 0603 X5R 10V | GRM188R61A105KA61D | Murata | 2 | 0.08 | 0.16 | Mouser 81-GRM188R61A105KA61D | AP2112K input (C17) / output (C18) | C15849
C19-C20 | Cap 100nF X2 film 275VAC THT | X2 film 100nF 275VAC, 13x6 mm body, 10 mm pitch (e.g. WIMA MKX2) | Vishay / KEMET | 2 | 0.40 | 0.80 | Mouser | Relay contact EMC snubbers (series with R19/R20); X2 mandatory (230 VAC); DNP per channel for LED/contactor loads; footprint C_Rect_L13.0mm_W6.0mm_P10.00mm — verify body size of chosen part
PCB | 2-layer FR4 ENIG 100x100mm, SMD assembly top side (qty 5) | Custom | JLCPCB | 1 | 1.50 | 1.50 | jlcpcb.com | JLCPCB fab + SMD assembly: run tools/jlc_export.py, upload fab/gerbers.zip + bom_jlc.csv + cpl_jlc.csv
HDR1 | 2.54mm 1x4 debug header | PEC04SAAN | Sullins | 1 | 0.20 | 0.20 | Mouser 538-22-28-4040 | UART0 TX RX + GND + 3V3
U6 | Ambient light sensor I2C 4-pin 6.8x2.35x3.0mm top view | VEML7700-TT | Vishay | 1 | 0.80 | 0.80 | Mouser 782-VEML7700-TT | I2C addr 0x10 (fixed). Footprint sensor_hub:VEML7700_TT (datasheet 84286 p.10) | C1850416
Q2 | P-channel MOSFET SOT-23 | BSS84PXUMA1 | Infineon | 1 | 0.10 | 0.10 | Mouser 771-BSS84PXUMA1 | PIR power gate (GP12); Vgs(th) -0.8 to -2.5V; Id -130mA; source→3V3_DIG drain→PIR VCC | C152212
J9 | Wago 2-pole push-in PCB terminal 3.5mm pitch | 2601-1102 | Wago | 1 | 0.70 | 0.70 | Distrelec / Wago direct | VSYS + GND PCB-side input (was Phoenix screw terminal); connects to Bulgin PX0441 panel connector via short cable; price est.
 |  | TOTAL |  |  |  | 31.08 |  | Excluding enclosure and cable glands; DNP items at 0.00; two 230 VAC relays + 7× Wago + X2 snubbers

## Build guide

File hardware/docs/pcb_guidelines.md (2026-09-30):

# PCB Layout Guidelines

Board: **100 × 100 mm** (was 100 × 80; enlarged Sep 2026 to fit the 8 mm MAINS separation and the socketed Pico WH — still inside the ≤ 100 × 100 mm low-cost fab tier), 2-layer FR4 1.6 mm, ENIG finish, 1 oz copper both layers. Enclosure is 3D-printed to fit.

**Design rules live in the project:** net classes in `kicad/sensor_hub.kicad_pro` (Default 0.25/0.15, Power 0.5, VSYS 0.8, MAINS 3.0 mm tracks) and custom rules in `kicad/sensor_hub.kicad_dru` (MAINS ↔ SELV 8 mm clearance + creepage + hole clearance, MAINS K1 ↔ K2 4 mm, same channel 1.5 mm). Rule areas on the board: `MAINS_keepout` (no pour, no vias), `PicoW_antenna_keepout` (no pour, no tracks; only between the Pico pin rows, x 33.0–46.8). Pours: `GND` (both layers), `GND_ANA` (analog column), `GUARD_PH` (PH_BUF, around the pH input). Custom DRC rule: socket/header GND pins (U1, J11) may use one thermal spoke per layer.

**Design decision (Sep 2026): relay contacts are rated for 230 VAC mains.** Anything up to 48 V DC is covered by the same layout. The board is therefore split into a **SELV side** (everything low-voltage, including the pH and NTC probes that sit in water) and a **MAINS zone** (relay contacts, snubbers, W6/W7). The two are separated by **reinforced insulation**.

**Hard requirements:**
- Two on-board relays (K1 + K2) with reinforced coil-to-contact insulation (Omron G2RL-1-E)
- **8 mm creepage and clearance** between any mains copper and any SELV copper, on both layers
- Routed isolation slot between the MAINS zone and the SELV side
- Guard pour on the pH high-Z node (NODE_A), driven by the AD8603 output
- RC snubbers on both relay contact sets (COM–NO), X2 capacitors
- Both relay contacts use mains-rated Wago connectors in the MAINS zone (W6 = RELAY1, W7 = RELAY2), physically separated from sensor ports W1–W5

---

## Zone Map

```
  x=0                                                                          x=100 mm
  ┌──────────────────────────────────────────────────────────────────────────────┐ y=0
  │(H1)  [J9 5V IN]  R10/R11  ┌──────────────┐  Q1 D2 ┌── K1 coil ──┐          (H4)│
  │                          │              │   R8  │  ═══slot═══ │               │
  │ C13 C11 C14 C17 C8       │  RASPBERRY   │       │ C19 R19     │  ┌────────┐   │
  │ U5 (LDO)                 │   PI PICO WH │       │  K1 contacts│══│ W6 (J7)│   │
  │ C15 C18 C12              │  on sockets  │       │  NC/COM/NO  │  └────────┘   │
  │ U2 (ADS1115) C7 C16      │              │ MAINS │ ! 230 VAC   │     MAINS     │
  │  ANALOG                  │  USB at top  │ ZONE  │  K2 contacts│  ┌────────┐   │
  │[BNC J1]  R1 D1 U4 ◄guard │ antenna end ▼│ ≥8 mm │ C20 R20     │══│ W7(J10)│   │
  │ (pH, left edge)  R2 R3 C1│  (keepout)   │       │  ═══slot═══ │  └────────┘   │
  │                          └──────────────┘  Q3 D3└── K2 coil ──┘               │
  │                          [J11 spare-GPIO holes]   R18                         │
  │                              (H5)                     [HDR1 UART]             │
  │  R7 C6 (NTC)           (H6) [U6] (H7)  ◄ light pipe       R17 Q2              │
  │                               C9                  Sensor Hub V2.0             │
  │                  R5          R6          R9                                   │
  │ ┌──J8──┐┌──J2──┐┌──J3──┐┌──J4──┐┌──J5──┐┌──J6──┐                              │
  │ │EC/NTC││ W1   ││ W2   ││ W3   ││ W4   ││ W5   │    all SELV, wire entry ↓   │
  │(H2)────┘└──────┘└──────┘└──────┘└──────┘└──────┘                         (H3) │
  └──────────────────────────────────────────────────────────────────────────────┘ y=100
```

Schematic only, not to scale — `kicad/sensor_hub.kicad_pcb` is the reference (placement comes from `tools/place_pcb.py`). Coordinates in this document are board mm from the top-left corner, y pointing down.

The relay bodies straddle the SELV/MAINS boundary: coil pins on the SELV side (K1 at the top edge, K2 at the bottom of the relay block), contact pins in the MAINS zone, with a 2 mm isolation slot under each relay body between them. The contact rows line up with the W6/W7 terminal rows so every mains track is a straight 3 mm run.

---

## Analog Zone Rules + Guard Ring

1. **No GND pour under the pH front-end**: under AD8603, R1 (10 MΩ), D1 (BAV99) and the NODE_A trace there is no GND/GND_ANA pour on either layer — the guard pour below takes its place. No digital signal routing in this area.

2. **Guard pour on NODE_A (mandatory)** — zone `GUARD_PH`, net PH_BUF, both layers, x 15.8–28.2 / y 45.0–51.2, priority above GND_ANA:
   - NODE_A (R1 → AD8603 IN+ and D1) is hand-routed short and sits inside the guard with 0.3 mm clearance.
   - The guard is driven **only** by AD8603 OUT (PH_BUF, unity-gain buffered). The bottom-layer guard is stitched to PH_BUF with one via next to U4 pin 4.
   - Do **not** connect the guard to GND or any other net.
   - Top-side guard copper is **exposed** (F.Mask opening = guard fill shrunk 0.1 mm, minus footprint silkscreen, generated by `route_pcb.py`): solder mask absorbs moisture, bare ENIG does not. NODE_A and all other copper stay masked. Clean flux off this area after assembly (IPA).
   - Purpose: potential difference ≈ 0 → surface leakage from nearby 3V3_ANA/GND_ANA copper ends on the guard, not on NODE_A. Outdoors an unguarded 10 GΩ surface path to 3V3 would already mean ≈ 1 pH of drift.

3. **VREF filter**: place C1 (100 nF on VREF_MID) directly at the divider midpoint node, not at the op-amp pin.

4. **Ground plane**: GND_ANA pour on both layers over the analog column (x 0.3–27.6, y 11–77.5), GND pour everywhere else. The two meet at a single point: net tie NT1 next to the ADS1115 (no 0 Ω link or ferrite needed).

5. **BNC connector**: right-angle mount at left board edge. The board edge should align with the enclosure wall knockout. Leave 3 mm clearance between BNC body and any component.

6. **AP2112K (U5)**: top-left, below J9, at the boundary between analog and digital zones. Its output connects to 3V3_ANA pour. Input from VSYS (5 V) — a 3.3 V LDO cannot regulate from 3V3_DIG.

---

## Digital Zone Rules

7. **Pico WH on sockets**: U1 uses `Module:RaspberryPi_Pico_Common_THT` (2 × 20 THT, 1 mm drill) for two 1×20 female headers, so a Pico WH (pre-soldered headers) plugs in and can be swapped. Stack height ≈ 8.5 mm socket + Pico — plan the 3D-printed enclosure for it. Keep the Pico W antenna end (opposite the USB connector) pointing away from the MAINS zone, with no copper pour and no traces under the antenna area on either layer.

7a. **J11 spare-GPIO breakout**: 2×8 holes at 2.54 mm (no part fitted) next to U1, carrying GP4–GP7, GP18–GP22, GP26–GP28, RUN, 3V3_DIG and 2× GND. Keep traces short; GP26–28 are ADC-capable (0–3.3 V only). SELV side only.

8. **ADS1115**: place at the analog/digital boundary. AGND pad connects to GND_ANA; VDD connects to 3V3_ANA; SDA/SCL to GND_DIG. 100 nF decoupling within 0.5 mm of VDD pin.

9. **EC front-end**: removed in v1 (LMP91200 EOL); GP4–GP7 stay free on J11 for the v2 AD5933.

10. **VEML7700 (U6) + light pipe**: U6 sits in the digital area below J11 (centre x 45 / y 73.45 mm) so a light pipe (acrylic rod) can run straight up to a window in the lid. Three M2 holes (H5–H7, r = 7 mm, one above, two diagonally below U6) take a 3D-printed light-pipe holder; M2 screws from below into the print (or M2 heat-set inserts). Keep the holder area free of tall parts. C9 (100 nF) directly below U6, inside the hole triangle. I2C address fixed at 0x10.

11. **I2C pullups**: R10 and R11 (4.7 kΩ) sit next to the Pico W GP2/GP3 pins (top, left of U1), not at the sensor end.

---

## Relay Zone Rules (230 VAC mains, two relays + EMC snubbers)

The insulation between MAINS and SELV must be **reinforced** because the SELV side connects to probes immersed in water and to touchable sensor wiring. Figures below follow IEC 60664-1 for 250 V, pollution degree 3 (outdoor enclosure, condensation possible), FR4 material group IIIa, overvoltage category II/III.

12. **Relays (K1 + K2)**: Omron G2RL-1-E (5 V coil, 16 A, 5 kVAC coil–contact, reinforced). Place at the right side so each relay's **coil pins sit on the SELV side and its contact pins sit in the MAINS zone**. Do not substitute a relay with only basic coil–contact insulation (e.g. Songle SRD series).

13. **SELV ↔ MAINS separation (reinforced)**:
    - **≥ 8.0 mm creepage** (along the board surface) and **≥ 8.0 mm clearance** (through air) between any mains net (K1/K2 COM, NO, NC, snubber nodes, W6/W7 pins) and any SELV net (coil, VSYS, GND, logic, sensors) — on **both** layers.
    - Measure from pad/trace edge to pad/trace edge, including THT pads on the opposite layer.
    - Use a KiCad **netclass `MAINS`** with a custom DRC rule (8 mm clearance to all other netclasses) so the DRC enforces this automatically.

14. **Isolation slot**: route a **2 mm wide slot** (Edge.Cuts) under each relay body between its coil pins and contact pins, and continue it along the MAINS/SELV boundary as far as the layout allows. A slot ≥ 1.5 mm wide counts as an air gap for creepage at pollution degree 3. The slot does not replace the 8 mm — it adds margin.

15. **MAINS zone keepout**:
    - No GND pour, no copper pour of any kind, and no vias on either layer in the MAINS zone, except the mains traces themselves.
    - No SELV trace may enter or cross under the MAINS zone on any layer.
    - No mounting hole with a metal screw inside or within 8 mm of the MAINS zone.
    - Silkscreen a hatched border and a ⚠ 230 V warning symbol around the MAINS zone.

16. **Between the two mains channels**: ≥ 4 mm between K1 circuit copper and K2 circuit copper (they may be fed from different circuits or phases). Between COM, NO and NC of the same relay (functional insulation, 230 V across an open contact): ≥ 3 mm wherever the relay footprint allows.

17. **Flyback diodes**: place D2 (1N4148W) directly across K1 coil pads and D3 directly across K2 coil pads. Cathode toward VSYS. SELV side only.

18. **Drivers**: Q1 (BC817) for K1 adjacent to K1 coil pins; Q3 (BC817) for K2 adjacent to K2 coil pins. Base resistors R8 and R18 (1 kΩ) within 3 mm of the respective base pads. G2RL coil draws ≈ 80 mA at 5 V — within BC817 rating.

19. **Contact EMC snubbers (mandatory)**:
    - R19 (100 Ω, 1206) + C19 (100 nF **X2** film, 275 VAC) in series across K1 COM–NO
    - R20 (100 Ω, 1206) + C20 (100 nF **X2** film, 275 VAC) in series across K2 COM–NO
    - Place as close as possible to the relay contact pins, entirely inside the MAINS zone.
    - Purpose: suppress arcing and EMI when switching inductive loads (pumps, solenoids, valves).
    - Note: at 230 V / 50 Hz a 100 nF snubber passes ≈ 7 mA with the contact **open**. This can make LED lamps glow or small contactor coils hum, and the NO terminal is never truly dead while COM is live. For such loads, leave R19/C19 (or R20/C20) unpopulated. Always isolate the supply before working on the load.

20. **Contact connectors**: W6 (K1) and W7 (K2) are 3-pole, mains-rated, THT PCB terminals for up to 2.5 mm² wire (Wago 236-403, 24 A IEC / 300 V 15 A UL). They sit at the **right board edge** (J7 at y 15–33, J10 at y 33–51), level with the relay contact rows, inside the MAINS zone and far from the SELV terminals along the bottom edge. Pin order follows the straight tracks: **W6 (J7) 1 = NO, 2 = COM, 3 = NC; W7 (J10) 1 = NC, 2 = COM, 3 = NO** (K2 is rotated 180°). Labels NC/COM/NO are printed on the tracks next to each terminal.

21. **External protection**: each relay channel must be protected upstream by a fuse or MCB rated ≤ 6 A (installation side, done by the electrician). The board traces are sized for 5 A continuous.

---

## Power Entry

22. J9 (VSYS + GND, Wago 2601-1102 push-in) at the top-left board edge, on the SELV side, far from the MAINS zone. Route VSYS as a 0.8 mm wide trace or polygon from J9 to Pico W VSYS and both relay coils. Add 10 µF + 100 nF directly at J9.

23. AP2112K input/output both need 10 µF + 100 nF. Place caps within 2 mm of IC pads.

---

## Trace Widths

Widths as set in the project (netclass default width; board minimum 0.2 mm, clearance 0.15 mm):

| Net type | Netclass | Width |
|---|---|---|
| Signal (logic, I2C, 1-Wire) | Default | 0.25 mm (0.24 mm where `fixclear` trimmed a Freerouting track) |
| Power (3V3_DIG, 3V3_ANA, GND) | Power | 0.5 mm (0.25 mm only for the first 1.2 mm off U2 pin 8, 0.5 mm pitch) |
| VSYS | VSYS | 0.8 mm |
| Relay contacts / mains (COM, NO, NC → W6/W7) | MAINS | **3.0 mm** (5 A continuous, 1 oz, ≈ 10 °C rise) |
| Snubber branch (R19/C19, R20/C20) | MAINS | 0.8–1.0 mm (hand-routed) |
| pH analog (NODE_A) | Default | 0.25 mm inside the guard pour |

Mains traces: keep them as short as possible (relay pin → Wago pin). Where 3.0 mm does not fit between pads, run the same trace on both layers in parallel and stitch at the THT pads rather than necking down.

---

## Silkscreen

All labels are generated by `tools/place_pcb.py`:

- Sensor terminals, above each terminal (the Wago bodies cover their own outline): `J2  W1 DS18B20`, `J3  W2 DHT22`, `J4  W3 PIR`, `J5  W4 GP16`, `J6  W5 GP17`; the separate J2–J6 reference fields are hidden.
- NTC terminal: `J8  EC  W Y R B` (W/Y unused in v1, R = NTC+, B = NTC–).
- Power: `5V IN` next to J9.
- Mains: `W6 RELAY1` / `W7 RELAY2` beside the terminals, `NC` / `COM` / `NO` on each mains track, `! 230 VAC max 5 A` between the relays.
- BNC: `PH`. Board name and date: `Sensor Hub V2.0  2026-09`.
- Not done yet: hatched border + ⚠ symbol around the MAINS zone (optional, the text warning is there).

---

## Manufacturing Checklist (before ordering)

- [ ] DRC passes with 0 errors (including the `MAINS` netclass 8 mm rule) — `hardware/tools/autoroute.sh` prints the summary; only the 12 `silk_edge_clearance` warnings (edge-mounted terminals) are expected
- [ ] Minimum trace/space ≥ 0.2 mm / 0.15 mm
- [ ] Minimum via drill ≥ 0.3 mm
- [ ] BNC, relay and Wago footprints match physical parts (print 1:1 and test-fit)
- [ ] ≥ 8 mm creepage and clearance between MAINS zone and SELV copper, both layers
- [ ] 2 mm isolation slot under each relay and along the MAINS/SELV boundary (in Edge.Cuts)
- [ ] No pour, vias or SELV traces inside the MAINS zone
- [ ] Mains traces ≥ 3.0 mm wide
- [ ] Guard pour present on both layers, connected only to AD8603 OUT (PH_BUF), top side exposed
- [ ] Snubbers (R19/C19 and R20/C20) placed close to relay contacts; C19/C20 are X2 rated
- [ ] Five sensor Wagos (W1–W5) on the SELV side; W6/W7 inside the MAINS zone
- [ ] 4× M3 mounting holes H1–H4 in the corners (3.2 mm, no copper), none within 8 mm of the MAINS zone
- [ ] 3× M2 light-pipe holder holes H5–H7 around U6 (2.2 mm, no copper)
- [ ] Order files regenerated: `python3 hardware/tools/jlc_export.py` → `fab/gerbers.zip` (all layers incl. paste + drill), `fab/bom_jlc.csv`, `fab/cpl_jlc.csv`
- [ ] Part orientation checked in the JLCPCB placement preview (U2, U4, U5, U6, D1–D3, Q1–Q3)
- [ ] Mains side reviewed by the electrician before first power-up

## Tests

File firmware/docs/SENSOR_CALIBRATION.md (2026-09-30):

# Sensor Calibration Guide

Practical guide for reliable calibration of the sensors used in the Sensor Hub (pH, EC, temperature, humidity).  
Designed so calibration can be triggered from the web dashboard with a simple button / wizard while the actual math runs in the firmware background.

The calibration parameters are stored in `config.json` (or a dedicated calibration section) and applied on every reading.

---

## 1. pH Sensor

**Hardware:** ADS1115 AIN0 → voltage from pH probe (via LMP or direct analog front-end).

**Current firmware model** (`sensors/ph.py`):
```python
cal = { "v_at_ph4": float, "v_at_ph7": float }

slope = (7.0 - 4.0) / (v7 - v4)
ph = 7.0 + slope * (v - v7)
```
This is a classic **2-point linear calibration** between pH 4 and pH 7.

### Recommended procedure

1. **Prepare**
   - Fresh buffer solutions: pH 4.00 / 4.01 and pH 7.00 (optionally also pH 10.00 for 3-point).
   - Use separate clean containers. Never pour used buffer back into the bottle.
   - Rinse the probe thoroughly with distilled / deionized water between solutions. Gently blot dry (do not rub the glass bulb).

2. **Temperature**
   - Bring buffers and probe to the same temperature (ideally 20–25 °C).
   - The firmware does not yet apply Nernst temperature compensation on the slope. For best accuracy keep temperature close to the calibration temperature or add compensation later.

3. **Calibration steps (2-point)**
   - Immerse probe in **pH 7.00** buffer.
   - Wait until the voltage reading is stable (drift < ~1–2 mV over 30–60 s).
   - Record `v_at_ph7`.
   - Rinse → immerse in **pH 4.00 / 4.01** buffer → wait for stability → record `v_at_ph4`.

4. **Optional 3-point**
   - Add pH 10.00 buffer.
   - Firmware currently uses only two points. Extending to piecewise linear or least-squares fit is straightforward.

5. **Quality check**
   - After calibration, put the probe back into pH 7. It should read 7.00 ± 0.05.
   - Calculate slope: `(7-4)/(v7-v4)`. Typical healthy glass electrodes give roughly 50–60 mV per pH unit (≈ 0.05–0.06 V/pH depending on the front-end gain).

**Frequency:** Weekly during continuous use, or after any longer storage / cleaning.

**Storage tip:** Keep the pH probe wet in KCl storage solution when not in use.

---

## 2. EC / Conductivity Sensor

> **Not available on the v1 board.** The LMP91200 front-end was removed (EOL); GP13/GP14 are unconnected and ADS1115 AIN3 is not wired. A v2 board with an AD5933 is planned. The procedure below applies once an EC front-end exists.

**Hardware (as originally designed):** LMP91200 AFE + ADS1115 AIN3 (signal) + AIN1 (NTC temperature compensation), excitation via complementary PWM on GP13/GP14.

**Current firmware model** (`sensors/ec.py`):
```python
cal = {
    "cell_constant": float,   # K in cm⁻¹
    "ref_voltage": float,     # usually 1.65 V
    "ref_temp_c": float       # usually 25.0
}
```
Temperature compensation is already implemented at 2 %/°C relative to `ref_temp_c`.

### Recommended procedure

1. **Prepare**
   - Standard solutions, e.g. 1413 µS/cm (and optionally 12.88 mS/cm for a second point).
   - Distilled / deionized water for rinsing.
   - Ensure the sensor is clean and free of air bubbles.

2. **Dry / zero point (optional but recommended)**
   - Hold the probe in air (completely dry).
   - Confirm near-zero reading.

3. **Calibration steps**
   - Rinse thoroughly with distilled water until the reading is very low.
   - Immerse in the 1413 µS/cm solution. Gently move the probe to remove bubbles.
   - Wait for temperature equilibrium and stable voltage.
   - Record the raw voltage / calculate the required `cell_constant` so that the compensated result equals 1413 µS/cm at the measured temperature.
   - For higher accuracy, repeat with a second standard (e.g. 12.88 mS/cm) and average or use a linear fit.

4. **Temperature**
   - The NTC on AIN1 already provides compensation. Make sure the NTC is thermally coupled to the conductivity cell.

**Frequency:** Every 2–4 weeks or when readings look suspicious.

---

## 3. Temperature Sensor

**Hardware:** DS18B20 (1-Wire on GP8, Wago W1) + NTC probe on J8 pins 3/4 (ADS1115 AIN1) for local compensation.

### Recommended procedure

Most digital sensors (DS18B20) are factory-calibrated to ±0.5 °C. For higher accuracy:

**1-point offset (simple)**
- Place sensor next to a trusted reference thermometer at room temperature.
- `offset = T_ref - T_sensor`
- Store and apply: `T_corrected = T_raw + offset`

**2-point (gain + offset)**
- Ice bath (0.0 °C) and boiling water (≈100 °C, correct for altitude) or two controlled baths.
- Calculate:
  ```
  gain   = (T_ref2 - T_ref1) / (T_raw2 - T_raw1)
  offset = T_ref1 - gain * T_raw1
  T_corrected = gain * T_raw + offset
  ```

Store `gain` and `offset` in the calibration config.

**Frequency:** Every few months or when comparing against a known good thermometer.

---

## 4. Humidity Sensor (DHT22 / similar)

### Recommended procedure – Saturated salt solutions

This is the most practical and reliable DIY method.

| Salt | Approx. % RH at 25 °C |
|---|---|
| Lithium chloride (LiCl) | ~11 % |
| Magnesium chloride (MgCl₂)  | ~33 % |
| Sodium chloride (NaCl) | ~75 % |
| Potassium chloride (KCl) | ~85 % |
| Potassium sulphate (K₂SO₄)  | ~97 % |

**Steps**
1. Make a saturated slurry (salt + a little distilled water) in a small container.
2. Place the slurry and the humidity sensor inside a sealed airtight box.
3. Leave for 12–24 hours so equilibrium is reached (temperature must be stable).
4. Record the sensor reading and the known RH value of the salt.
5. Calculate offset (and optionally gain if you do two points, e.g. 33 % + 75 %).

Apply linear correction in firmware the same way as for temperature.

**Frequency:** Every 1–3 months.

---

## Dashboard / One-Button Calibration Workflow

Goal: User only presses a button and follows simple on-screen instructions. All math and storage happen in the background.

### Suggested flow

1. User opens **Calibration** page / modal in the dashboard.
2. Selects the sensor (pH / EC / Temperature / Humidity).
3. Wizard appears:
   - Clear instruction (“Rinse probe → immerse in pH 7.00 buffer”).
   - Live raw reading + stability indicator (e.g. “Stable for 15 s”).
   - Button **“Capture this point”**.
4. After all required points are captured, firmware / server calculates the calibration coefficients.
5. Coefficients are written to persistent storage (`config.json` or a dedicated calibration file / database table).
6. Confirmation screen shows the new slope / offset / cell constant and a quick verification reading.
7. Optional: log calibration event with timestamp and previous values for audit trail.

### Implementation notes for this project

- Firmware already accepts calibration dictionaries for pH and EC.
- Extend `config.json` (or a separate `calibration.json`) with the fields shown above.
- Add a command endpoint (similar to the existing relay commands) that puts the device into “calibration mode” and accepts the captured points.
- On the dashboard side, a simple multi-step modal is enough; no complex state machine is required.
- Always apply temperature compensation where possible (already present for EC).

---

## Reliability Best Practices

- Always use **fresh** calibration solutions.
- Rinse thoroughly between points with distilled water.
- Wait for true stability (temperature + sensor drift).
- Record temperature of the calibration solutions.
- After calibration, verify with a third independent solution or known reference.
- Monitor slope / cell constant over time – large changes indicate aging or contamination of the sensor.
- Store calibration history (timestamp + coefficients) so drift can be tracked.
- For pH: never let the probe dry out.

---

## Quick Reference – Calibration Frequency

| Sensor | Recommended interval | Critical failure modes |
|---|---|---|
| pH | Weekly (or after storage) | Electrode aging, contamination  |
| EC | 2–4 weeks | Dirty cell, air bubbles |
| Temperature  | Every few months | Rare |
| Humidity | 1–3 months | Drift, contamination |

---

## Related files in this repository

- `firmware/src/sensors/ph.py` – 2-point pH math
- `firmware/src/sensors/ec.py` – EC + NTC temperature compensation
- `firmware/tests/test_calibration.py` – unit tests for the calibration formulas
- `firmware/src/config.json` – place to store calibration coefficients

Feel free to extend the firmware with a dedicated calibration state machine and corresponding dashboard UI. The math is already solid and tested.

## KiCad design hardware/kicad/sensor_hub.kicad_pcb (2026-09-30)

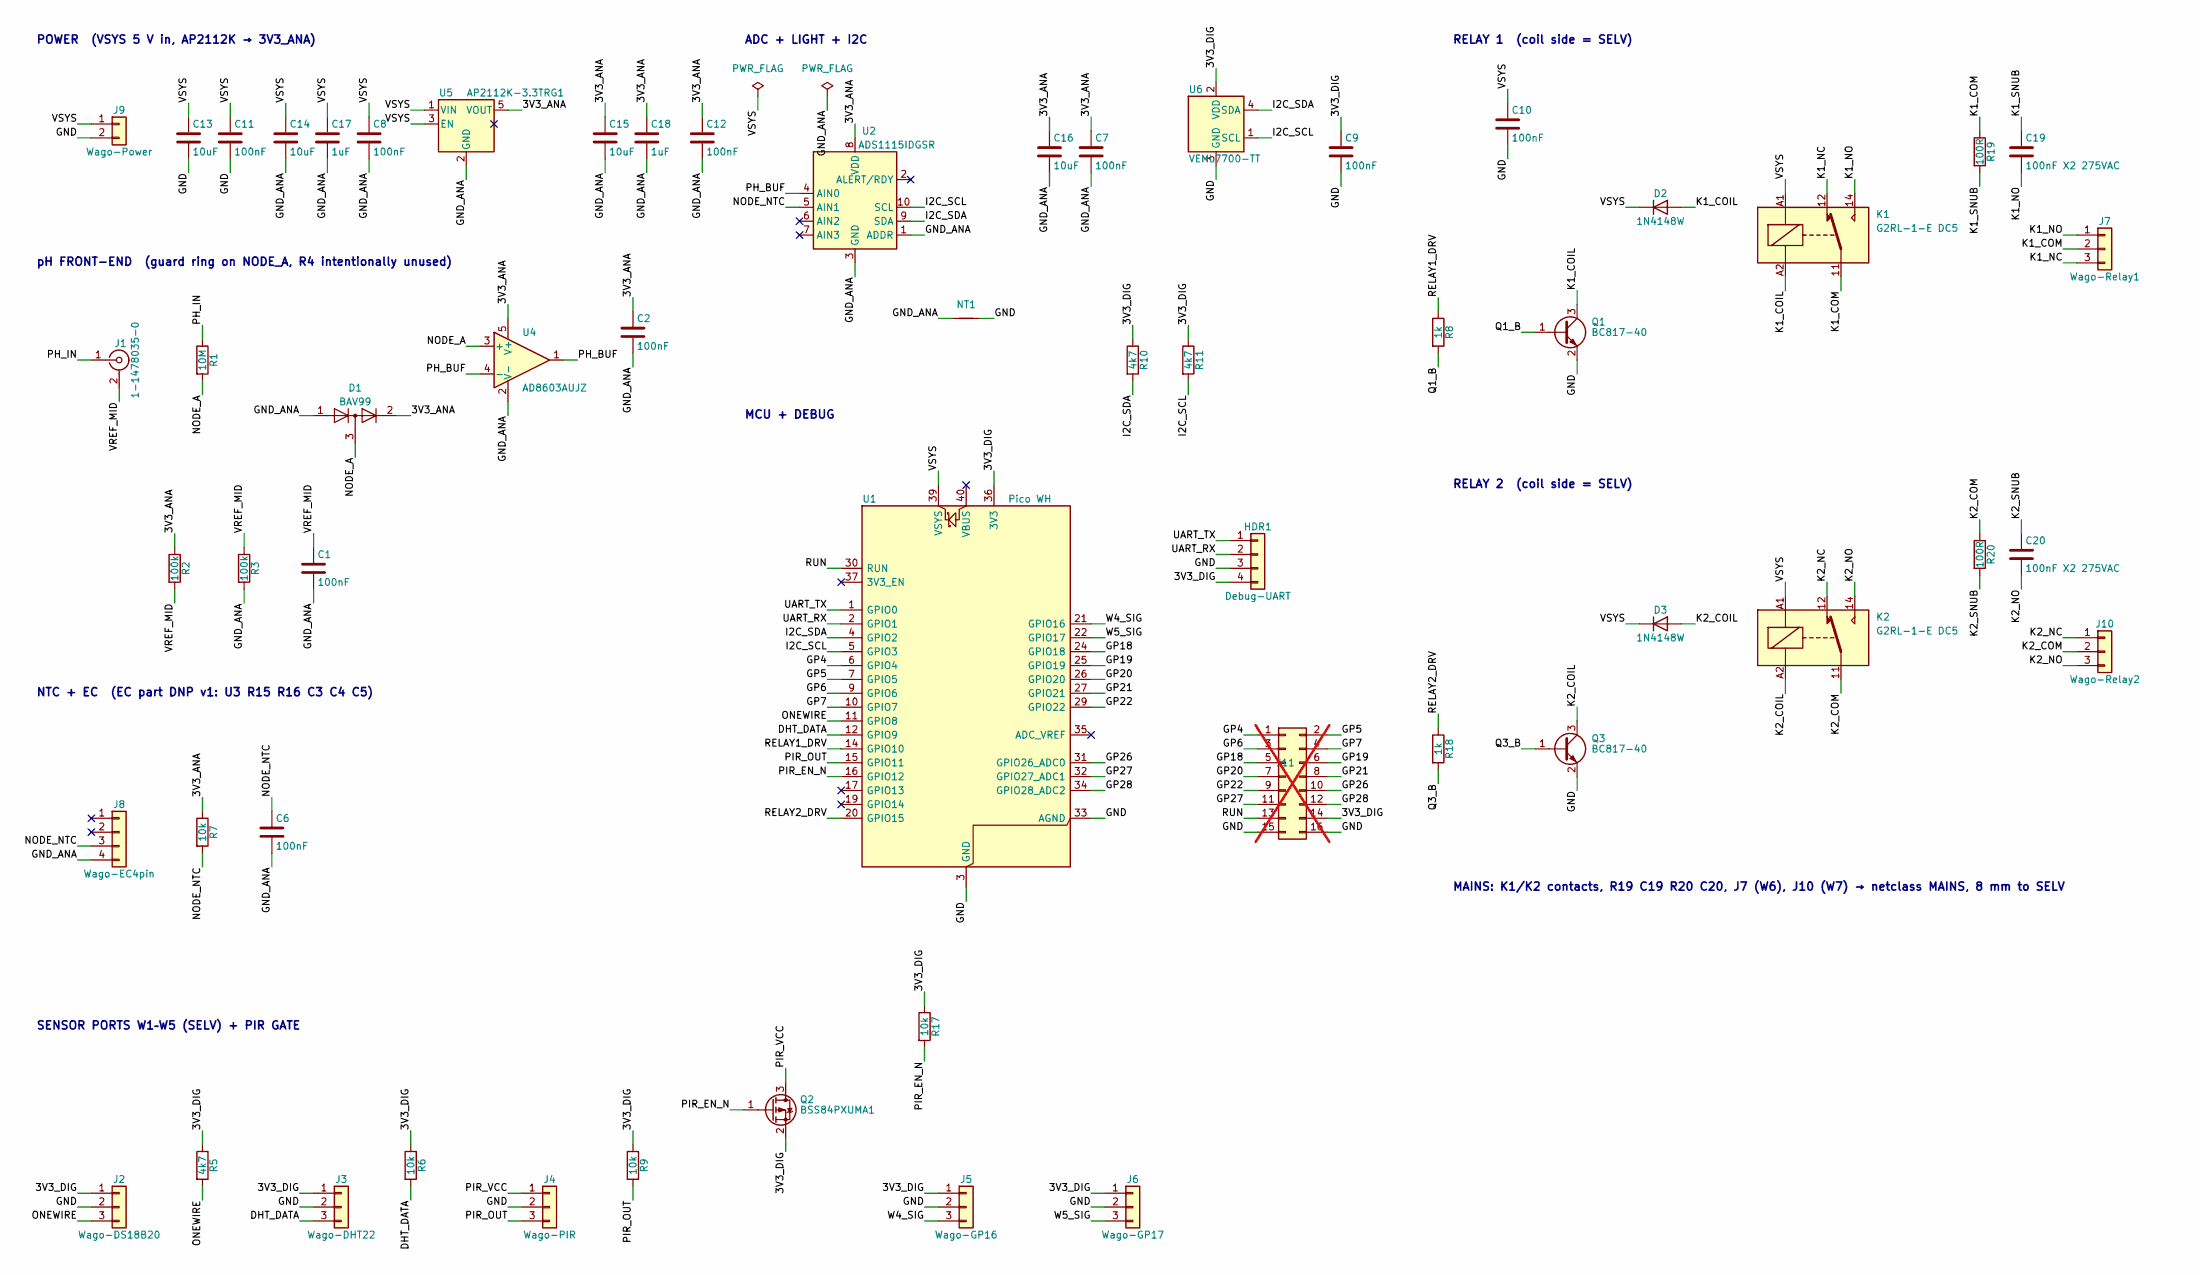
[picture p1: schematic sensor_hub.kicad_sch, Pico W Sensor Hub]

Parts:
C1, C2, C6, C7, C8, C9, C10, C11, C12: 100nF; C_0603_1608Metric
C13, C14, C15, C16: 10uF; C_0805_2012Metric
C17, C18: 1uF; C_0603_1608Metric
C19, C20: 100nF X2 275VAC; C_Rect_L13.0mm_W6.0mm_P10.00mm_FKS3_FKP3_MKS4
D1: BAV99; SOT-23
D2, D3: 1N4148W; D_SOD-123
HDR1: Debug-UART; PinHeader_1x04_P2.54mm_Vertical
J1: 1-1478035-0; BNC_TEConnectivity_1478035_Horizontal
J2: Wago-DS18B20; TerminalBlock_WAGO_2601-1103_1x03_P3.50mm_Horizontal
J3: Wago-DHT22; TerminalBlock_WAGO_2601-1103_1x03_P3.50mm_Horizontal
J4: Wago-PIR; TerminalBlock_WAGO_2601-1103_1x03_P3.50mm_Horizontal
J5: Wago-GP16; TerminalBlock_WAGO_2601-1103_1x03_P3.50mm_Horizontal
J6: Wago-GP17; TerminalBlock_WAGO_2601-1103_1x03_P3.50mm_Horizontal
J7: Wago-Relay1; TerminalBlock_WAGO_236-403_1x03_P5.00mm_45Degree
J8: Wago-EC4pin; TerminalBlock_WAGO_2601-1104_1x04_P3.50mm_Horizontal
J9: Wago-Power; TerminalBlock_WAGO_2601-1102_1x02_P3.50mm_Horizontal
J10: Wago-Relay2; TerminalBlock_WAGO_236-403_1x03_P5.00mm_45Degree
J11: Spare-GPIO; PinHeader_2x08_P2.54mm_Vertical; not fitted
K1, K2: G2RL-1-E DC5; Relay_SPDT_Omron_G2RL-1-E
NT1: NetTie_2; NetTie-2_SMD_Pad0.5mm
Q1, Q3: BC817-40; SOT-23
Q2: BSS84PXUMA1; SOT-23
R1: 10M; R_0603_1608Metric
R2, R3: 100k; R_0603_1608Metric
R5, R10, R11: 4k7; R_0603_1608Metric
R6, R7, R9, R17: 10k; R_0603_1608Metric
R8, R18: 1k; R_0603_1608Metric
R19, R20: 100R; R_1206_3216Metric
U1: Pico WH; RaspberryPi_Pico_Common_THT
U2: ADS1115IDGSR; MSOP-10_3x3mm_P0.5mm
U4: AD8603AUJZ; TSOT-23-5
U5: AP2112K-3.3TRG1; SOT-23-5
U6: VEML7700-TT; VEML7700_TT

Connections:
/3V3_ANA: C2.1, C7.1, C12.1, C15.1, C16.1, C18.1, D1.2 (A), R2.1, R7.1, U2.8 (VDD), U4.5 (V+), U5.5 (VOUT)
/3V3_DIG: C9.1, HDR1.4, J2.1, J3.1, J5.1, J6.1, J11.14, Q2.2 (S), R5.1, R6.1, R9.1, R10.1, R11.1, R17.1, U1.36 (3V3), U6.2 (VDD)
/DHT_DATA: J3.3, R6.2, U1.12 (GPIO9)
/GND: C9.2, C10.2, C11.2, C13.2, HDR1.3, J2.2, J3.2, J4.2, J5.2, J6.2, J9.2, J11.15, J11.16, NT1.2, Q1.2 (E), Q3.2 (E), U1.3 (GND), U1.8 (GND), U1.13 (GND), U1.18 (GND), U1.23 (GND), U1.28 (GND), U1.33 (AGND), U1.38 (GND), U6.3 (GND)
/GND_ANA: C1.2, C2.2, C6.2, C7.2, C8.2, C12.2, C14.2, C15.2, C16.2, C17.2, C18.2, D1.1 (K), J8.4, NT1.1, R3.2, U2.1 (ADDR), U2.3 (GND), U4.2 (V-), U5.2 (GND)
/GP4: J11.1, U1.6 (GPIO4)
/GP5: J11.2, U1.7 (GPIO5)
/GP6: J11.3, U1.9 (GPIO6)
/GP7: J11.4, U1.10 (GPIO7)
/GP18: J11.5, U1.24 (GPIO18)
/GP19: J11.6, U1.25 (GPIO19)
/GP20: J11.7, U1.26 (GPIO20)
/GP21: J11.8, U1.27 (GPIO21)
/GP22: J11.9, U1.29 (GPIO22)
/GP26: J11.10, U1.31 (GPIO26_ADC0)
/GP27: J11.11, U1.32 (GPIO27_ADC1)
/GP28: J11.12, U1.34 (GPIO28_ADC2)
/I2C_SCL: R11.2, U1.5 (GPIO3), U2.10 (SCL), U6.1 (SCL)
/I2C_SDA: R10.2, U1.4 (GPIO2), U2.9 (SDA), U6.4 (SDA)
/K1_COIL: D2.2 (A), K1.A2, Q1.3 (C)
/K1_COM: J7.2, K1.11, R19.1
/K1_NC: J7.3, K1.12
/K1_NO: C19.2, J7.1, K1.14
/K1_SNUB: C19.1, R19.2
/K2_COIL: D3.2 (A), K2.A2, Q3.3 (C)
/K2_COM: J10.2, K2.11, R20.1
/K2_NC: J10.1, K2.12
/K2_NO: C20.2, J10.3, K2.14
/K2_SNUB: C20.1, R20.2
/NODE_A: D1.3 (K), R1.2, U4.3 (+)
/NODE_NTC: C6.1, J8.3, R7.2, U2.5 (AIN1)
/ONEWIRE: J2.3, R5.2, U1.11 (GPIO8)
/PH_BUF: U2.4 (AIN0), U4.1, U4.4 (-)
/PH_IN: J1.1 (In), R1.1
/PIR_EN_N: Q2.1 (G), R17.2, U1.16 (GPIO12)
/PIR_OUT: J4.3, R9.2, U1.15 (GPIO11)
/PIR_VCC: J4.1, Q2.3 (D)
/Q1_B: Q1.1 (B), R8.2
/Q3_B: Q3.1 (B), R18.2
/RELAY1_DRV: R8.1, U1.14 (GPIO10)
/RELAY2_DRV: R18.1, U1.20 (GPIO15)
/RUN: J11.13, U1.30 (RUN)
/UART_RX: HDR1.2, U1.2 (GPIO1)
/UART_TX: HDR1.1, U1.1 (GPIO0)
/VREF_MID: C1.1, J1.2 (Ext), R2.2, R3.1
/VSYS: C8.1, C10.1, C11.1, C13.1, C14.1, C17.1, D2.1 (K), D3.1 (K), J9.1, K1.A1, K2.A1, U1.39 (VSYS), U5.1 (VIN), U5.3 (EN)
/W4_SIG: J5.3, U1.21 (GPIO16)
/W5_SIG: J6.3, U1.22 (GPIO17)

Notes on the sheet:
RELAY 1 (coil side = SELV)
ADC + LIGHT + I2C
MCU + DEBUG
NTC + EC (EC part DNP v1: U3 R15 R16 C3 C4 C5)
SENSOR PORTS W1–W5 (SELV) + PIR GATE
pH FRONT-END (guard ring on NODE_A, R4 intentionally unused)
RELAY 2 (coil side = SELV)
MAINS: K1/K2 contacts, R19 C19 R20 C20, J7 (W6), J10 (W7) → netclass MAINS, 8 mm to SELV
POWER (VSYS 5 V in, AP2112K → 3V3_ANA)

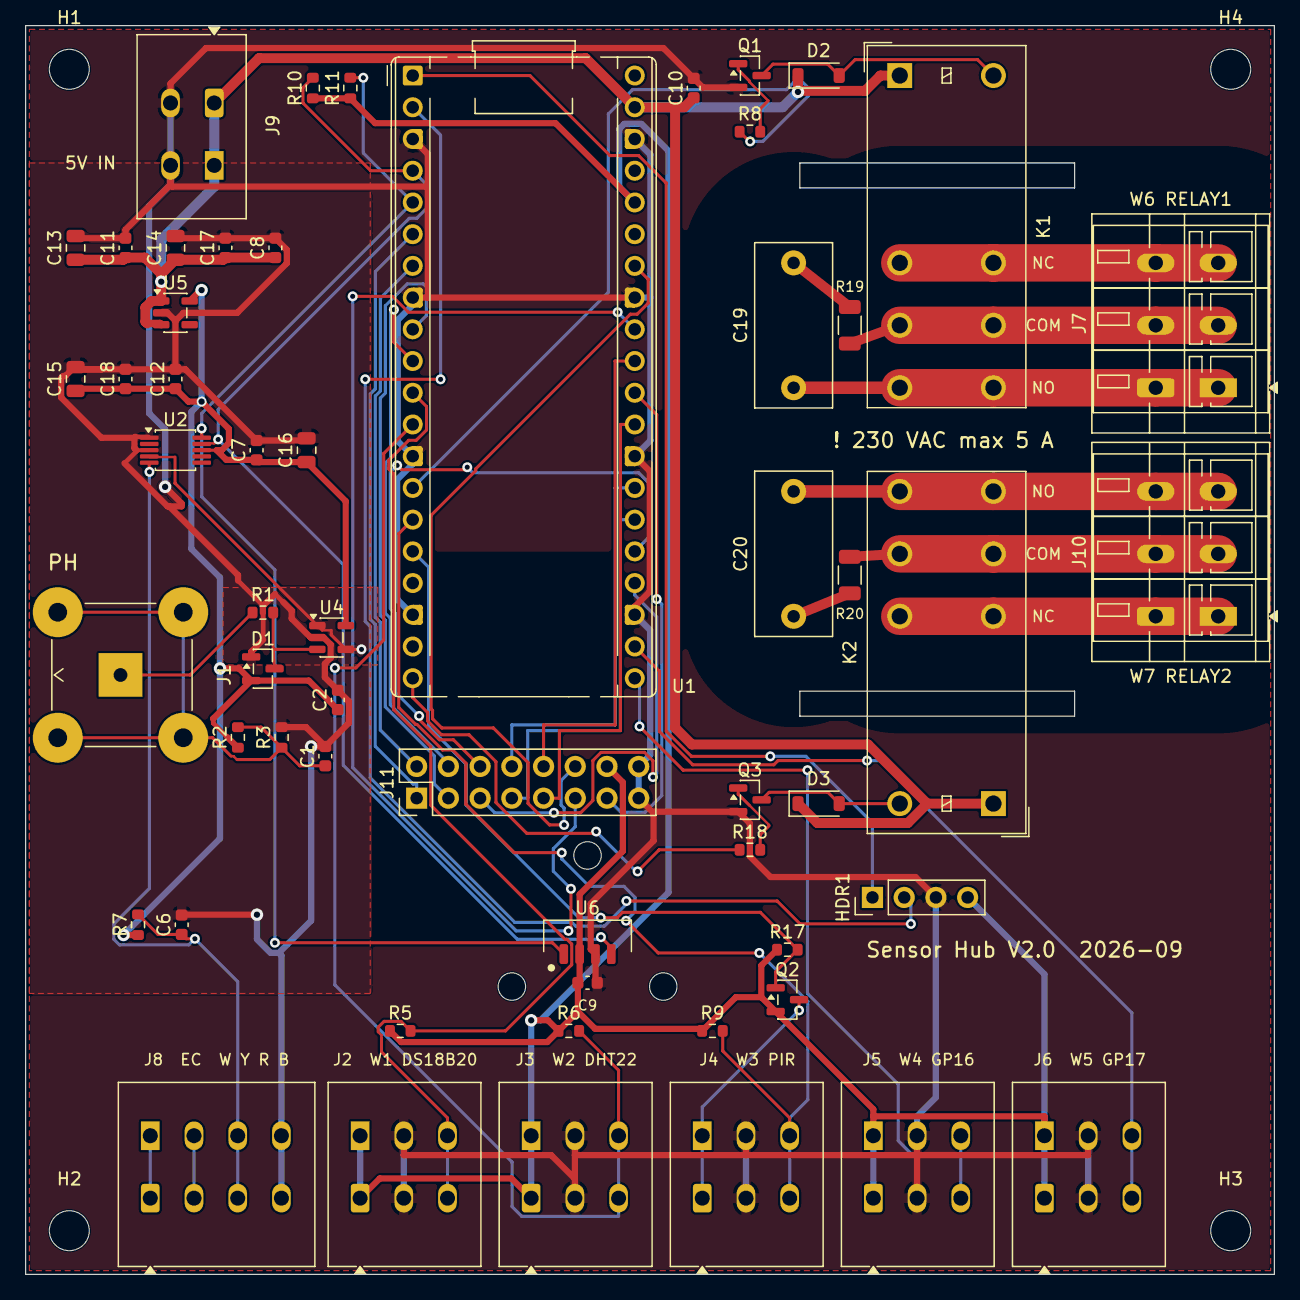
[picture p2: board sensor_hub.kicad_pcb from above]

Board: 2 copper layers, 100.0 x 100.0 mm, 64 parts (0 on the bottom side), 48 nets.

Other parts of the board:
H1, H2, H3, H4: MountingHole_3.2mm_M3
H5, H6, H7: MountingHole_2.2mm_M2

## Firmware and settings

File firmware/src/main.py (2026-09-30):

"""Boot and scheduler loop for the Pico W sensor hub."""

import gc
import json
import time
from machine import I2C, SPI, Pin, PWM

from drivers.ads1115 import ADS1115
from drivers.lmp91200 import LMP91200
from drivers.relay import Relay
import sensors.ph as ph_sensor
import sensors.ec as ec_sensor
import sensors.temperature as temp_sensor
import sensors.humidity as hum_sensor
import sensors.light as light_sensor
import sensors.motion as motion_sensor
import sensors.soil as soil_sensor
import sensors.probe_temp as probe_temp_sensor
import sensors.water_level as water_level_sensor
from communication import wifi, time_sync, protocol
from storage.ringbuffer import RingBuffer
from power import manager as power
from automation.control import handle_relays

# On-board relays (hardware/docs/schematic.md): K1 via Q1 on GP10, K2 via Q3 on GP15
RELAY_PINS = {1: 10, 2: 15}


def load_config():
    with open("config.json") as f:
        return json.load(f)


def init_hardware(cfg):
    s = cfg["sensors"]
    ads = lmp = pwm_a = pwm_b = i2c = None

    needs_ads = s.get("ph", {}).get("enabled") or s.get("probe_temp", {}).get("enabled")
    needs_i2c = needs_ads or s.get("light", {}).get("enabled")
    if needs_i2c:
        i2c = I2C(1, sda=Pin(2), scl=Pin(3), freq=400_000)
        if needs_ads:
            ads = ADS1115(i2c)

    if s.get("ec", {}).get("enabled"):
        spi = SPI(0, baudrate=1_000_000, polarity=0, phase=0,
                  sck=Pin(6), mosi=Pin(5), miso=Pin(4))
        cs = Pin(7, Pin.OUT, value=1)
        lmp = LMP91200(spi, cs)
        pwm_a = PWM(Pin(13), freq=2000, duty_u16=0)
        pwm_b = PWM(Pin(14), freq=2000, duty_u16=0)

    if s.get("motion", {}).get("enabled"):
        motion_sensor.start(warmup_s=s["motion"].get("warmup_s", 60))

    max_on_s = cfg["relay"]["max_on_duration_s"]
    relays = {n: Relay(pin_num=pin, max_on_s=max_on_s) for n, pin in RELAY_PINS.items()}
    return ads, lmp, pwm_a, pwm_b, relays, i2c


def read_all_sensors(cfg, ads, lmp, pwm_a, pwm_b, i2c):
    s = cfg["sensors"]
    cal = cfg["calibration"]
    reading = {}

    if s["ph"]["enabled"]:
        reading["ph"] = ph_sensor.read(ads, cal["ph"], channel=s["ph"]["ads_channel"])

    if s["ec"]["enabled"]:
        reading["ec_us"] = ec_sensor.read(ads, lmp, cal["ec"], pwm_a, pwm_b)

    if s["temperature"]["enabled"]:
        reading["temp_c"] = temp_sensor.read()

    if s["humidity"]["enabled"]:
        h, t = hum_sensor.read()
        reading["humidity_pct"] = h
        if reading.get("temp_c") is None:
            reading["temp_c"] = t   # fallback if DS18B20 absent

    if s["light"]["enabled"]:
        reading["lux"] = light_sensor.read(i2c)

    if s["soil"]["enabled"]:
        reading["soil_pct"] = soil_sensor.read(s["soil"], cal["soil"])

    if s["motion"]["enabled"]:
        reading["motion"] = motion_sensor.read()

    if s.get("probe_temp", {}).get("enabled"):
        reading["probe_temp_c"] = probe_temp_sensor.read(
            ads, cal["probe_temp"], channel=s["probe_temp"].get("ads_channel", 1))

    if s.get("water_level", {}).get("enabled"):
        reading["water_level"] = water_level_sensor.read(s["water_level"])

    reading["ts"] = time.time()
    return reading


def run_upload_cycle(cfg, reading, buf, ack_id=None):
    """Connect WiFi, time-sync, upload buffer + current reading, poll commands.
    Returns (commands, new_interval_s) — new_interval_s is None if unchanged.
    """
    srv = cfg["server"]
    wifi_cfg = cfg["wifi"]

    vbus_mv = protocol.vsys_mv()  # measure before WiFi uses GPIO29

    connected = wifi.connect(wifi_cfg["ssid"], wifi_cfg["password"],
                             timeout_s=wifi_cfg["timeout_s"])
    if not connected:
        buf.push(reading)
        return [], None

    uptime = power.uptime_ms()
    new_cfg = time_sync.sync(srv["url"], cfg["device_id"], uptime, timeout_s=srv["timeout_s"])

    if ack_id is not None:
        protocol.ack_command(srv["url"], ack_id, srv)

    readings_to_send = buf.peek_all() + [reading]
    stored = protocol.upload_readings(
        srv["url"], cfg["device_id"], cfg["fw_version"],
        vbus_mv, readings_to_send, srv
    )
    if stored is not None:
        buf.clear()
    else:
        buf.push(reading)

    commands = protocol.poll_commands(srv["url"], cfg["device_id"], srv)
    wifi.disconnect()
    return commands, new_cfg


def main():
    led = Pin("LED", Pin.OUT)
    try:
        cfg = load_config()
    except Exception as e:
        print("config.json load failed:", e)
        while True:
            for _ in range(5):
                led.value(1); time.sleep_ms(100)
                led.value(0); time.sleep_ms(100)
            time.sleep_ms(2000)

    ads, lmp, pwm_a, pwm_b, relays, i2c = init_hardware(cfg)
    buf = RingBuffer(max_slots=cfg["storage"]["buffer_slots"])

    interval_s = cfg["poll_interval_s"]
    ack_id = None

    while True:
        try:
            led.value(1)
            reading = read_all_sensors(cfg, ads, lmp, pwm_a, pwm_b, i2c)
            print("Reading:", reading)

            commands, new_cfg = run_upload_cycle(cfg, reading, buf, ack_id)
            if new_cfg:
                if "interval_s" in new_cfg:
                    interval_s = new_cfg["interval_s"]
                if "relay_schedule" in new_cfg:
                    cfg["relay_schedule"] = new_cfg["relay_schedule"]
            ack_id = handle_relays(commands, relays, reading, cfg)
        except Exception as e:
            import sys
            sys.print_exception(e)
        finally:
            led.value(0)
            gc.collect()
            print("free mem:", gc.mem_free())

        power.sleep(interval_s, relays=relays.values())


main()

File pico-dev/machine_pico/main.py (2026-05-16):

"""
Machine Pico — UART bridge + relay controller
Wiring: UART1 TX=GPIO4 → Project Pico RX=GPIO1
        UART1 RX=GPIO5 ← Project Pico TX=GPIO0
        GPIO15 → Relay1 IN  (LOW = relay closed = RUN pulled to GND = reset)
        GPIO28 → Relay2 IN  (LOW = relay closed = light ON)

Commands (normal mode):
  RESET         — pulse relay1 100 ms → hard-reset Project Pico
  SEND:<text>   — write <text>\\r\\n to Project Pico via UART
  BRIDGE        — enter transparent passthrough mode (USB ↔ UART1)
  LIGHT_ON      — close light relay (GPIO28 LOW)
  LIGHT_OFF     — open light relay (GPIO28 HIGH)
  LIGHT_TOGGLE  — toggle light relay

Bridge mode:
  All USB bytes are forwarded to UART1 and vice versa with no processing.
  This lets mpremote (or any tool) talk directly to the Project Pico's
  UART0 REPL. Exit by sending 5× Ctrl-C in a row.
"""
import machine
import utime
import sys
import uselect
import micropython

BAUD     = 115200
RESET_MS = 100

uart  = machine.UART(1, baudrate=BAUD, tx=machine.Pin(4), rx=machine.Pin(5))
relay = machine.Pin(15, machine.Pin.OUT, value=1)
light = machine.Pin(28, machine.Pin.OUT, value=1)   # active-LOW; 1 = off

_poll = uselect.poll()
_poll.register(sys.stdin, uselect.POLLIN)


def relay_reset(ms=RESET_MS):
    relay.value(0)
    utime.sleep_ms(ms)
    relay.value(1)


def usb_write(msg):
    sys.stdout.write(msg)


# ── Bridge mode ───────────────────────────────────────────────────────────────

def run_bridge():
    """
    Transparent USB↔UART passthrough. mpremote can connect to this port and
    talk directly to the Project Pico's UART0 REPL (Pico W default primary
    REPL stream). Exit: send 5× Ctrl-C in a row.
    """
    usb_write("[bridge] BRIDGE MODE — 5x Ctrl-C to exit\r\n")

    # Disable MicroPython's own Ctrl-C interrupt so we can forward \x03 raw.
    micropython.kbd_intr(-1)

    exit_count = 0

    try:
        while True:
            # UART → USB: forward Project Pico output
            n = uart.any()
            if n:
                chunk = uart.read(n)
                # latin-1: lossless 1-to-1 byte↔char mapping for raw bytes
                sys.stdout.write(chunk.decode("latin-1"))

            # USB → UART: forward mpremote / tool input
            if _poll.poll(0):
                try:
                    ch = sys.stdin.read(1)
                except UnicodeError:
                    continue
                uart.write(ch.encode("latin-1"))

                if ch == "\x03":          # Ctrl-C
                    exit_count += 1
                    if exit_count >= 5:
                        break
                else:
                    exit_count = 0

            utime.sleep_ms(1)
    finally:
        micropython.kbd_intr(3)           # re-enable Ctrl-C
        usb_write("\r\n[bridge] bridge mode ended\r\n")


# ── Normal command mode ───────────────────────────────────────────────────────

usb_write("[bridge] ready — RESET | SEND:<text> | BRIDGE | LIGHT_ON | LIGHT_OFF | LIGHT_TOGGLE\r\n")

_cmd_buf = ""

while True:
    # Forward Project Pico UART output → USB
    n = uart.any()
    if n:
        chunk = uart.read(n)
        usb_write(chunk.decode("latin-1"))

    # Read USB commands (non-blocking)
    if _poll.poll(0):
        try:
            ch = sys.stdin.read(1)
        except UnicodeError:
            continue

        if ch in ("\r", "\n"):
            cmd = _cmd_buf.strip()
            _cmd_buf = ""

            if not cmd:
                pass

            elif cmd == "RESET":
                relay_reset()
                usb_write("[bridge] RESET sent\r\n")

            elif cmd.startswith("SEND:"):
                payload = cmd[5:]
                uart.write(payload + "\r\n")
                usb_write("[bridge] TX: " + payload + "\r\n")

            elif cmd == "BRIDGE":
                run_bridge()

            elif cmd == "LIGHT_ON":
                light.value(0)
                usb_write("[bridge] light ON\r\n")

            elif cmd == "LIGHT_OFF":
                light.value(1)
                usb_write("[bridge] light OFF\r\n")

            elif cmd == "LIGHT_TOGGLE":
                light.value(1 - light.value())
                usb_write("[bridge] light " + ("ON" if light.value() == 0 else "OFF") + "\r\n")

            else:
                usb_write("[bridge] unknown: " + cmd + "\r\n")

        else:
            _cmd_buf += ch

    utime.sleep_ms(1)

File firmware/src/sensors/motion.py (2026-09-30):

"""
PIR motion sensor on GP11, powered through Q2 (BSS84, P-channel) on GP12.

GP12 LOW = PIR powered, HIGH = off; R17 keeps it off while GP12 floats at boot.
While motion is enabled the PIR stays powered (AM312 / HC-SR501 idle current is
well under 0.1 mA) and an IRQ latches every rising edge on GP11, so a reading
reports "motion since the last reading" instead of a short scan window. The
edge also wakes the Pico from lightsleep. Edges during the PIR's warm-up after
power-on are ignored.
"""

from machine import Pin
import time

_pir = None
_ready_at = None
_seen = False


def _on_edge(pin):
    global _seen
    if time.ticks_diff(time.ticks_ms(), _ready_at) >= 0:
        _seen = True


def start(pir_pin_num=11, gate_pin_num=12, warmup_s=60):
    """Power the PIR and arm the edge latch. Call once at boot."""
    global _pir, _ready_at, _seen
    Pin(gate_pin_num, Pin.OUT, value=0)   # LOW = Q2 on = PIR powered
    _pir = Pin(pir_pin_num, Pin.IN)
    _ready_at = time.ticks_add(time.ticks_ms(), warmup_s * 1000)
    _seen = False
    _pir.irq(trigger=Pin.IRQ_RISING, handler=_on_edge)


def read():
    """
    Return True if motion was seen since the last read, False if not,
    None while the PIR is still warming up or start() was not called.
    """
    global _seen
    if _pir is None or time.ticks_diff(time.ticks_ms(), _ready_at) < 0:
        return None
    try:
        detected = _seen or bool(_pir.value())
        _seen = False
        return detected
    except Exception:
        return None

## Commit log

2026-05-11 hardware: generate KiCad 8 schematic skeleton (59 components)
    hardware/tools/generate_schematic.py places all BOM components on an
    A3 sheet with correct references, values, footprints, and DNP flags.
    lib_symbols is empty — run Tools > Update Symbols from Library in
    KiCad 8 to resolve. Then wire per hardware/docs/schematic.md.
    Zone layout matches pcb_guidelines.md: analog left, EC (DNP) centre-
    left, digital centre, PIR gate, relay right, connectors along bottom.
    U3 (LMP91200) and U6 (VEML7700) may need manual symbol search if not
    in the user's installed KiCad libraries.
    [sensor_hub.kicad_sch]
2026-05-11 hardware: fix schematic generator component spacing
    Components were overlapping after symbol library resolution in KiCad.
    Rewrote COMPONENTS coordinates with ~2× more spacing: ICs get 30 mm+
    clearance, connectors at 45 mm intervals, Pico W isolated at right,
    EC DNP zone shifted to centre-left. Regenerated sensor_hub.kicad_sch.
    [sensor_hub.kicad_sch]
2026-05-13 firmware: fix SPI pin swap and make relay non-blocking
    SPI sck/miso were swapped in init_hardware (GP4=MISO, GP6=SCK per pinout).
    relay.on() now records a deadline and returns immediately instead of
    blocking with sleep_ms. power.sleep() wakes early when the relay deadline
    falls within the sleep window, ticks the relay off, then sleeps the
    remainder. Also wires up PIR IRQ so lightsleep can wake on GP11.
    [main.py, manager.py, relay.py]
2026-05-13 firmware: blink error pattern on config.json load failure
    Missing or corrupted config.json previously crashed the device with no
    visible indication. Now caught in main(); the LED flashes 5 rapid pulses
    every 2 s so the fault is visible without a serial connection.
    [main.py]
2026-05-13 server: add requirements.txt
    fastapi, uvicorn[standard], aiosqlite — the three runtime dependencies
    needed to deploy on the Raspberry Pi.
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2026-05-13 dashboard: refresh last_seen on every chart update
    updateLastSeen was only called on initial load. refresh() now re-fetches
    the device list so the timestamp stays current across auto-refresh cycles.
2026-05-13 server: validate action field as Literal["relay_on", "relay_off"]
    Previously any string was accepted. Pydantic now rejects unknown actions
    with a 422 before they reach the database.
2026-05-13 server: add index on commands(device_id, acked_at, created_at)
    The pending-commands query filters on device_id and acked_at IS NULL
    then sorts by created_at. Without an index this was a full table scan
    on every Pico poll.
2026-05-13 firmware: fix NTC ref voltage in EC temperature compensation
    _ntc_temp_c was receiving cal["ref_voltage"] (1.65 V, the LMP91200 TIA
    midpoint) as its supply rail, but the NTC pull-up is wired to 3V3_ANA
    (3.3 V). The two voltages serve different purposes. Introduced _NTC_VCC
    = 3.3 as a hardware constant so the Steinhart-Hart calculation uses the
    correct divider reference.
    [ec.py]
2026-05-13 firmware: rewrite tests to import actual sensor modules
    Tests previously copied the math from sensors/ rather than importing
    it, so a fix to the real code wouldn't change the test outcome.
    Now stubs machine/micropython before import and calls the real
    ph_sensor.read(), ec_sensor._ntc_temp_c(), ec_sensor.read(), and
    soil_sensor.read() via MockADS/MockPWM/MockLMP objects. Added
    test_ec_ntc (was implicit in old ntc test) and updated
    test_ec_temp_compensation to drive ec.read() end-to-end.
2026-05-14 hardware test: add water_level sensor, fix soil ADC, wire all three sensors
    - Board confirmed as Pico W (RP2040); firmware/CLAUDE.md updated with correct
    MicroPython build URL and chip verification instructions
    - soil.py rewritten to use machine.ADC(GP26) directly — no ADS1115 needed;
    calibration updated from real hardware readings (dry=65535, wet=9600)
    - water_level.py added (FS-IR1901D IR sensor on GP16, powered from VBUS 5V);
    first proof of the extensibility pattern: one file + two config lines, nothing
    else touched
    - main.py: hardware init now conditional on enabled sensors so missing hardware
    (ADS1115, LMP91200) does not crash boot; water_level sensor wired into read loop
    -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
    [main.py, soil.py, water_level.py]
2026-05-14 feature: time-based relay scheduling end-to-end
    Dashboard: schedule editor UI with time/duration/days/skip-if condition,
    save sends to server. Server: device_config table, /api/schedule/ GET+POST,
    time sync response includes relay_schedule. Firmware: evaluate_schedule()
    with 29-min window and _last_fired dedup, main loop applies schedule before
    sensor threshold rules. Also fixes water_level missing from chart SENSOR_META
    and schedule not loading after device selector initializes.
    [main.py, time_sync.py]
2026-05-14 firmware: fix main loop crash-and-stop on second cycle
    Wrap the while-True body in try/except so any unhandled exception
    prints a traceback and continues rather than silently killing the loop.
    Add gc.collect() + free-mem print after each cycle to catch memory
    exhaustion early. Improve lightsleep fallback to use time.sleep() and
    log when it triggers.
    [main.py, manager.py]
2026-05-14 firmware: fix VSYS ADC channel on Pico W
    ADC(3) reads GPIO3 (I2C SCL), not VSYS. On Pico W, VSYS is on
    GPIO29 via a 200k/100k divider. Use ADC(29) to get the correct
    ~4800-5000 mV USB voltage instead of ~44 mV garbage.
    [protocol.py]
2026-05-14 docs: add Pico W hardware notes to README
    Document VSYS ADC channel, measurement timing, lightsleep behaviour,
    monitor tooling, and flashing window — all found during bring-up.
2026-05-15 docs: update API contract + fix systemd unit for local machine
    - Add relay_schedule to POST /api/time response shape
    - Add GET/POST /api/schedule/{device_id} endpoints to contract
    - Update sensor_hub.service: user=mista, local paths, user service
    (system service blocked by SELinux user_home_t on Fedora/Bazzite;
    deploy as user service + loginctl enable-linger instead)
2026-05-15 firmware: add relay_off threshold rule support
    relay_off rules now cut the relay immediately when the sensor condition
    is met, regardless of the active timer. Off rules always evaluate before
    on rules so an upper bound (soil >= 60%) always wins over a lower bound
    (soil < 30%) in the same cycle.
    Default config: relay_off at soil >= 60%, relay_on at soil < 30%.
2026-05-15 tools: add Machine Pico UART debug bridge
    Two-Pico debug setup: Machine Pico (RP2350) acts as UART bridge and
    relay-based hardware reset controller for the Project Pico. Includes
    uart_debug.py (builtins.print mirror via UART0) and pico_tool.py
    (monitor/reset/flash CLI, auto-detects port by USB VID/PID).
    Also fixes boot.py crash on MicroPython builds without machine.SOFT_RESET.
    [main.py, pico_tool.py, uart_debug.py]
2026-05-15 tools: fix pico_tool monitor for non-TTY environments
    Handle missing TTY gracefully: isatty() check switches between
    interactive mode (keyboard→serial) and read-only stream mode.
    Wrap serial reads in try/except so the reader thread exits cleanly
    when the port closes instead of crashing with Bad file descriptor.
    [pico_tool.py]
2026-05-15 tools: fix flash via UART bridge; add BRIDGE passthrough mode
    Project Pico W (MicroPython default) uses UART0 as primary REPL, not USB.
    mpremote on ACM1 could not enter raw REPL because Ctrl-C/Ctrl-A were
    invisible to the device.
    Machine Pico now supports a BRIDGE command that enables transparent
    USB↔UART1 passthrough (micropython.kbd_intr(-1) to suppress Ctrl-C
    interception). pico_tool flash sends RESET then BRIDGE, then runs
    mpremote on ACM0 with `resume` (skips soft-reset to avoid boot.py
    5 s sleep timeout). Exit bridge mode with 5× Ctrl-C.
    [main.py, pico_tool.py]
2026-05-15 pico-dev: fix UnicodeError in bridge normal-mode UART forwarding
    MicroPython's bytes.decode() does not reliably support the 'replace'
    error handler; use latin-1 (lossless 1-to-1 byte mapping) consistent
    with the existing bridge mode.
    [main.py]
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2026-05-28 pico-dev: add boot.py, flash tool, and serial fix
    - boot.py: 5 s REPL window after hard reset for reliable USB flashing
    - flash_machine_pico.py: standalone flash script for machine Pico
    - pico_tool.py: disable DTR/RTS on serial open to prevent spurious resets;
    clarify flash-via-USB-port comments
    [flash_machine_pico.py, pico_tool.py]
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2026-08-19 Add sensor calibration guide (pH, EC, temperature, humidity)
    Comprehensive English documentation for reliable calibration procedures matching the existing firmware math, plus dashboard one-button workflow recommendations.
2026-08-20 Hardware: two on-board relays (K1+K2) as minimum for modular automation
    - schematic.md: second relay driver on GP15, netlist + Wago notes updated
    - bom.csv: K2, Q3, D3 + base resistor added
    - pcb_guidelines.md + hardware/CLAUDE.md: document two-relay requirement and layout rules
    - README.md: note dual-relay capability
    [bom.csv]
2026-08-20 Add relay contact EMC snubbers + strengthen guard-ring notes
    - schematic: RC snubber (100R + 100nF) across K1 and K2 contacts
    - bom: R19/R20 + C19/C20 for snubbers
    - explicit guard-ring implementation note for pH node
    [bom.csv]
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2026-08-20 Hardware: both relays use Wago connectors (W6=RELAY1, W7=RELAY2)
    - Remove separate J10 terminal; unify interface on bottom edge
    - schematic.md, bom.csv, pcb_guidelines.md updated accordingly
    [bom.csv]
2026-09-27 hardware: 230 VAC relay spec + sync schematic with docs
    - Relays switched to Omron G2RL-1-E (reinforced coil-contact insulation)
    for 230 VAC / 5 A per channel; 8 mm SELV-MAINS creepage/clearance,
    isolation slot, MAINS zone keepout, 3 mm mains traces, X2 snubbers
    - Schematic: add K2, Q3, R18, D3, R19/C19, R20/C20, J10 (W7); drop R4
    and second 10M on pH input; renumber pull-ups to one ref per function;
    fix symbol/footprint names for KiCad 10; upgrade file to KiCad 10
    - Add project symbol library with VEML7700
    - schematic.md gets a master reference designator list; BOM and
    footprints.md aligned; AP2112K fed from VSYS
    [bom.csv, sensor_hub.kicad_sch]
2026-09-27 hardware: restore values/footprints after symbol update, grid-snap and group schematic by block
    'Update Symbols from Library' had reset values, footprints and U1/HDR1
    references to library defaults; restored from the previous commit by
    symbol uuid. All symbols snapped to the 2.54 mm grid so wires land on
    pins, grouped into labelled functional blocks, stale notes removed.
    U4 footprint follows the KiCad symbol default (TSOT-23-5).
    [bom.csv, sensor_hub.kicad_sch]
2026-09-27 hardware: pick library-footprint parts for BNC, Wago ports and X2 snubbers
    - J1: Amphenol 031-6575 RA BNC
    - J2-J6 (W1-W5): Wago 2601-1103, 3.5 mm
    - J7/J10 (W6/W7 mains): Wago 236-403, 24 A IEC / 300 V 15 A UL
    - C19/C20: X2 100nF, 13x6 mm body, 10 mm pitch
    Only U6 (VEML7700) is still without a footprint.
    [bom.csv, sensor_hub.kicad_sch]
2026-09-27 hardware: wire the full schematic with net labels
    Every pin gets a short stub and a net label (no long wires across the
    sheet); unused pins get no-connect flags. Net tie NT1 joins GND_ANA and
    GND at the ADS1115, PWR_FLAGs on VSYS and GND_ANA. Netlist verified pin
    by pin against docs/schematic.md (197 pins, 0 mismatches). ERC: only the
    expected Pico GND/AGND power-output pair. Parts re-spaced so labels do
    not overlap. schematic.md: BAV99 pin 3 is the common node.
    [sensor_hub.kicad_sch]
2026-09-27 hardware: Pico WH on sockets, spare-GPIO breakout J11, VEML7700 footprint
    - U1 now uses Module:RaspberryPi_Pico_Common_THT so a Pico WH plugs into
    two 1x20 female headers (added to BOM)
    - J11: 2x8 solder-hole breakout (DNP) for GP4-7, GP18-22, GP26-28, RUN,
    3V3_DIG, GND
    - Project footprint sensor_hub:VEML7700_TT from Vishay datasheet 84286
    (top-view pad layout, 4 x 0.7x1.6 mm, 1.27 mm pitch); fp-lib-table added
    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
    [bom.csv, sensor_hub.kicad_sch]
2026-09-27 hardware: first board placement, outline and 230 VAC design rules
    - Board 100 x 100 mm (fits 8 mm MAINS separation + socketed Pico WH),
    4x M3 holes (board-only), 2 mm isolation slots: under the relays
    (coil | contacts) and along the MAINS zone boundary
    - Zone placement: power + ADC + pH top/left (BNC at left edge), Pico WH
    centre (USB at top), relays + W6/W7 + snubbers in MAINS zone top right,
    sensor ports along the bottom edge
    - Net classes (Default/Power/VSYS/MAINS) and sensor_hub.kicad_dru:
    MAINS<->SELV 8 mm clearance/creepage/hole clearance, K1<->K2 4 mm
    - Rule areas: MAINS (no pour/vias), pH high-Z (no pour), Pico W antenna
    - J1 changed to TE 1-1478035-0 (all shield pads = pad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
    [bom.csv, sensor_hub.kicad_pcb, sensor_hub.kicad_sch]
2026-09-28 hardware: upright relays with terminals aligned to contact rows, remap W6/W7 pins
    Claude-Session: https://claude.ai/code/session_01PDHupfXBxwLmo1MxXKJEdB
    [sensor_hub.kicad_pcb, sensor_hub.kicad_sch]
2026-09-28 hardware: route board (mains + NODE_A by hand, rest Freerouting), GND/GND_ANA/guard pours
    Antenna keepout narrowed to the area between the Pico pin rows; it covered
    pins 15-26 and made them unroutable. Still open: J11 GP20/21/22/26,
    3V3_ANA at U2, 5 dangling vias, B.Cu guard not stitched.
    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
    [sensor_hub.kicad_pcb]
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2026-09-28 hardware: complete routing, copper DRC clean
    - 3V3_ANA pre-routed off U2 pin 8 (0.5 mm pitch too tight for Power width)
    - J11 spare GPIOs pre-routed down the gap between antenna keepout and pin row
    - B.Cu guard pour stitched to PH_BUF next to U4
    - dangling vias/stubs stripped after Freerouting
    - place_pcb: antenna keepout only between the Pico pin rows
    - DRC: header/socket GND pins may use one thermal spoke per layer
    - route_pcb/autoroute: Delete instead of Remove (segfault), fail loudly
    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
    [sensor_hub.kicad_pcb]
2026-09-28 hardware: clean up silkscreen, update KiCad note for script workflow
    - W1-W5 port labels inside the terminal outlines, NC/COM/NO on the mains tracks
    - W6/W7, 5V IN, EC and board-name text moved clear of footprints and pads
    - C19/R19/R20 reference fields moved off neighbouring parts
    - place_pcb: Delete instead of Remove, detect texts via GetClass()
    (isinstance never matched, so reruns stacked duplicate labels)
    Only silk_edge_clearance left (edge-mounted terminals, clipped by the fab).
    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
    [sensor_hub.kicad_pcb]
2026-09-28 hardware: Wago push-in for J8/J9, exposed pH guard, JLCPCB SMD assembly files
    - J8 (EC) / J9 (5V in): Phoenix screw -> Wago 2601-1104 / 2601-1102, same
    family as J2-J6; power block moved down 3.5 mm, J2-J6 row shifted 0.6 mm
    - pH guard: top-side guard copper exposed (mask opening = fill - 0.1 mm,
    footprint silkscreen kept masked); CLAUDE.md analog-zone rules updated
    - route_pcb finish rerunnable (clears its own pours)
    - jlc_export.py + fab/: gerbers.zip, bom_jlc.csv, cpl_jlc.csv (39 SMD parts,
    17 LCSC lines, DNP and THT excluded); bom.csv gains an lcsc column
    - U4 order code fixed: AD8603AUJZ (ARTZ does not exist)
    Claude-Session: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
    [bom.csv, bom_jlc.csv, sensor_hub.kicad_pcb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]
2026-09-28 hardware: vendor 3D models for Wago terminals, relays and BNC
    KiCad ships no models for these parts. place_pcb points the footprints at
    ${KIPRJMOD}/3d/<name>.step with rotation/offset derived from the pin
    positions in the STEP files. The STEP files stay local (vendor terms,
    public repo): .gitignore'd, download list in hardware/kicad/3d/README.md.
    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
    [sensor_hub.kicad_pcb]
2026-09-28 hardware: port labels above the terminals, 2601-1103 model
    The W1-W5 / EC labels sat inside the terminal outlines and would be hidden
    under the soldered Wago bodies. Now above them as 'J2 W1 DS18B20' etc.,
    with the separate J2-J6/J8 reference fields hidden. fab/ re-exported.
    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
    [sensor_hub.kicad_pcb]
2026-09-29 hardware: drop EC front-end, U6 under a light pipe with M2 holder holes
    - U3 (LMP91200, EOL) and R15/R16/C3/C4/C5 removed from schematic, board and
    docs; GP13/GP14 now unused. NTC on J8 pins 3/4 unchanged.
    - U6 (VEML7700) + C9 moved to the digital area below J11 (x 45 / y 73.45)
    for a light pipe to the lid; H5-H7 = 3x M2 NPTH on r = 7 mm for a
    3D-printed holder (the band only fits M2, not M2.5).
    - autoroute: fixclear step narrows tracks that Freerouting leaves a few um
    under the clearance (0.25 -> 0.24 mm), routing unchanged.
    - schematic.md / bom.csv / footprints.md / pcb_guidelines.md updated;
    J8/J9 no longer listed as Phoenix. fab/ re-exported.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
    [bom.csv, sensor_hub.kicad_pcb, sensor_hub.kicad_sch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]
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2026-09-29 firmware: drive both on-board relays (K1 GP10, K2 GP15)
    - main: RELAY_PINS {1: 10, 2: 15}, one Relay (with safety timeout) each
    - automation/control.py (new): per-relay priority command > schedule >
    sensor rules; a command for one relay no longer blocks the other
    relay's automation. Moved out of main.py so it is testable on desktop.
    - rules: optional "relay": 1|2 on rules and schedule slots (default 1);
    evaluate_schedule returns all due slots, at most one per relay
    - power.sleep: wakes early for whichever relay's on-time ends first,
    never calls lightsleep(0)
    - tests/test_relays.py: 7 desktop tests (rules, schedule, commands,
    legacy/unknown relay, sleep wake-ups)
    - docs: relay secti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
    [main.py, manager.py]
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2026-09-30 firmware: fix PIR gate and lux scaling, add NTC probe temperature
    - motion: GP12 LOW powers the PIR (Q2 is P-channel); the old code had it
    inverted. The PIR now stays powered while enabled and an IRQ latches
    motion between readings, with a configurable warm-up (warmup_s)
    - power.sleep counts the time actually slept, so an IRQ wake no longer
    shortens the cycle
    - light: VEML7700 gain 1/8 + 25 ms is 2.1504 lux/count, plus Vishay's
    high-lux correction
    - probe_temp: NTC on J8 / ADS1115 AIN1 as probe_temp_c, read on the
    +-4.096 V range (the node passes 2.048 V below ~14 C); server column
    + migration, dashboard toggle, API contract
    - docs: float switch and capacitive soil comments, PIR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
    [ads1115.py, light.py, main.py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]
